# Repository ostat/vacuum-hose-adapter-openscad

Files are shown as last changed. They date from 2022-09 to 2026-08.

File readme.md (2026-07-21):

# Vacuum hose adapters for OpenSCAD

This is a collection of OpenSCAD modules that allow you to easily design and 3D
print adapters for pipes and tubes of various sizes. The main utilization of
these adapters is to connect a vacuum hose to a variety of different tools and
devices, such as power tools, sanders, and dust collectors.

This highly parametric module lets you create create custom adapters that
perfectly fit the dimensions of your vacuum hose and the tool or device you want
to connect it to. Besides fitting the dimensions, it is also possible to design
the adapters with a tapered shape that ensures a secure and snug fit, preventing
any air leaks that might reduce the suction power of your vacuum.

# Availability
Official availability
 - Online: https://hose-adapter.ostat.com/vacuum-hose-adapter
 - Printables: https://www.printables.com/model/316283-vacuum-nozzles-for-all-common-hose-sizes
 - MakerWorld: https://makerworld.com/en/models/481868-parametric-vacuum-hose-connector#profileId-396315

# Documentation
Official documentation
- https://docs.ostat.com/docs/openscad/hose-adapter

## Connection types

Three different types of connections are possible to maximize the number of
applications possible.

### Hose connection
Intended for connection between two hoses or a hose and a tool exhaust.

#### Main settings
* Diameter: Internal or external diameter of the intended connector.
* Length: The length of the connection end.
* Taper: the hose connection can be tapered to allow for a tighter fit.

### Flat connection
Intended for connection to a tool. To achieve this the transition section is set
to flat, the transition length becomes the thickness. The flat area will be from
connector1Diameter to connector2Diameter.

#### Main settings
* TransitionStyle: **flat**
* TransitionLength: Thickness of the flat area.

### Magnetic flange connection
Intended for creating a quick removable connection that holds in place using
magnets. Perfect for quick connect/disconnect to large shop equipment.

The magnets should be slightly recessed so that the two faces get a good seal,
allow extra depth if you want to avoid supports. Usually 8 10mm x 1.5mm magnets
seem sufficient to hold a 50mm connector for a shopvac.

#### Magnet polarity
If you plan on connecting two magnetic flanges together, pay attention to the
polarities of your magnets. A good way to ensure connection would be to
**alternate the polarity** when gluing the magnets. That way it will always be
possible to connect any magnetic flange to an other one.

#### Alignment ring
An alignment ring can be added to help align the duct and reduce air leakage.
Ideally, the flange should be created with a small recess to accept the ring.
The most optimal solution would be to print the ring in flexible material (TPU).

Although, this does not appear to be required to have a good suction.

#### Main settings
**Changing any of the settings** (diameter, magnet size, alignment ring...)
**will change the magnet position and flange size**.
A good practice would be to save the configuration of the hose in JSON using the
`save preset` option in OpenSCAD. See [the OpenSCAD
documentation][openscad_save_params] for more information.

* Flange diameter: Internal diameter of the flange connection.
* Flange thickness: The overall thickness of the flange. Magnet thickness plus
  4mm seem to work well.
* Connector length: The length of the connector before the tapered section will
  start.
* Magnet count: Number of magnets to be added to the flange.
* Magnet diameter: Diameter of the magnets (add 0.5 to measurement).
* Magnet border: The amount material around the magnet.
* Magnet thickness: Thickness of the magnets (add 0.5 to measurement, 1.0 to
  avoid supports).
* lip: If an alignment ring should be supported, can be recessed or protruding,
  suggest recessed.

## Sample files
The file [vacuum-hose-adapter-samples.scad](vacuum-hose-adapter-samples.scad
"more info"), has a few sample configurations to highlight the intended usages.

### 50mm hose to 30mm hose
An adapter to connect a 50mm (internal diameter) hose to a 30mm (internal
diameter) hose. A stop is added to the larger 50mm side, so the adapter does not
get pulled in to the hose. Both ends have a small taper to ensure snug fit.<br>
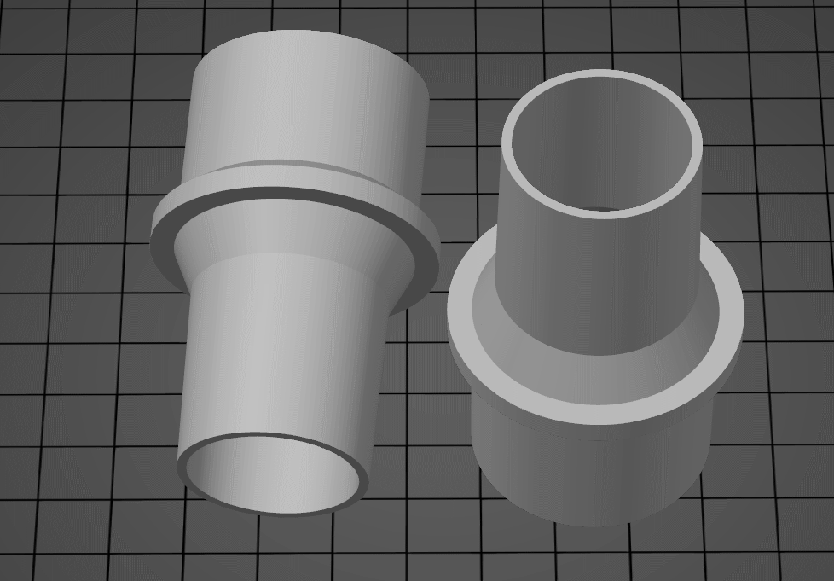
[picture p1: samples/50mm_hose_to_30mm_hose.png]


### 50mm hose to 100mm hose
An adapter to connect a 50mm (internal diameter) hose to a 100mm (internal
diameter) hose. A stop is added to the larger 100mm side, so the adapter does
not get pulled in to the hose. Both ends have a small taper to ensure snug
fit.<br>
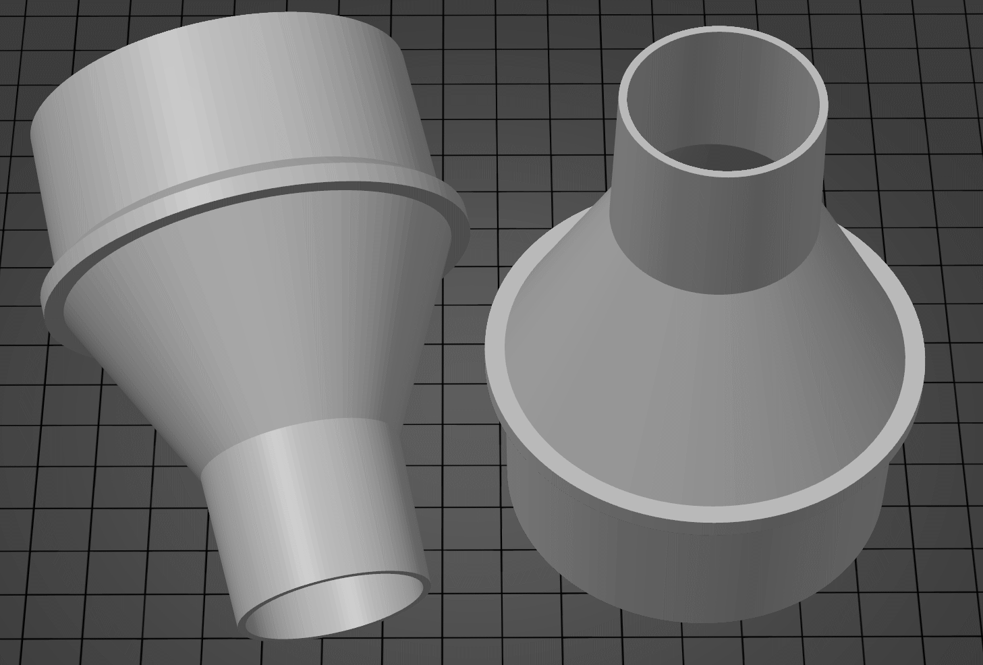
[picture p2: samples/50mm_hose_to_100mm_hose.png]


### Flat plate to 50mm hose
An adapter to connect a 50mm (internal diameter) host to the side of a something
else such as a large tool or machine. The end has a small taper.<br>
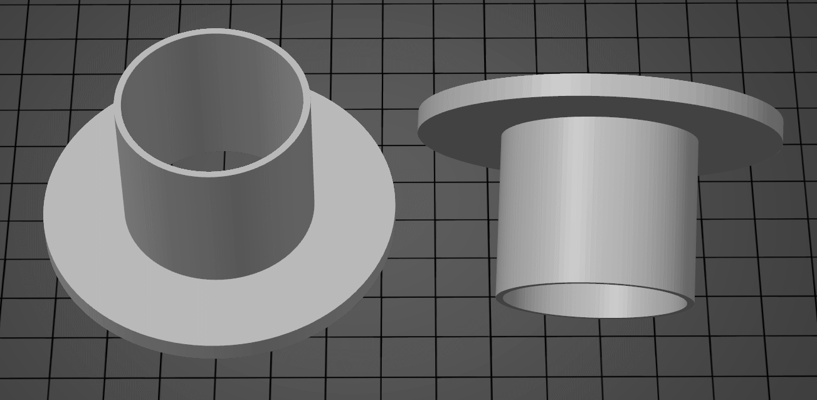
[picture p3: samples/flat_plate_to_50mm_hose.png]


### 50mm magnet to 40mm
A 50mm magnetic adapter to a 40mm hose. The magnetic flange has space for 8 10mm
x 2mm magnets (magnet holes are 10.5mm x 2.5mm). There is a recessed ring for an
alignment ring. The 40mm end has a 2mm taper.<br>
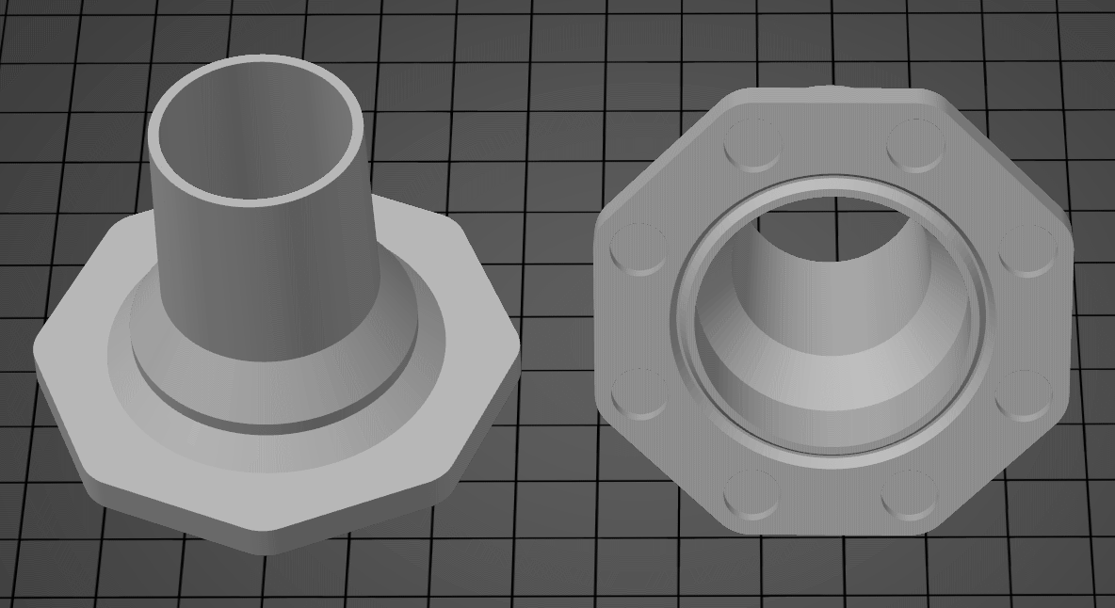
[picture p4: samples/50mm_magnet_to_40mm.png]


### 50mm magnet to 100mm
A 50mm magnetic adapter to a 100mm hose. The magnetic flange has space for 8
10mm x 2mm magnets (magnet holes are 10.5mm x 2.5mm). There is a recessed ring
for an alignment ring. The 100mm end has a 2mm taper.<br>
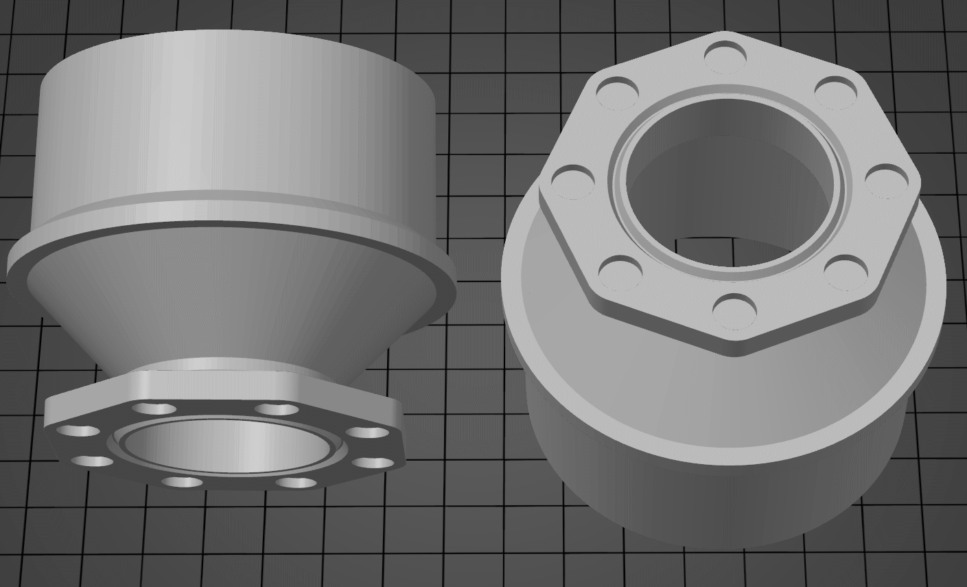
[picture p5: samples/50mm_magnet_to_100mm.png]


### 50mm magnet to flat plate with 30mm connector
A 50mm magnetic adapter to flat plate with 30mm connector. The magnetic flange
has space for 8 10 mm x 2mm magnets (magnet holes are 10.5mm x 2.5mm). This can
be used to for connecting to a tool that would have a hole the size of the
connector.<br>
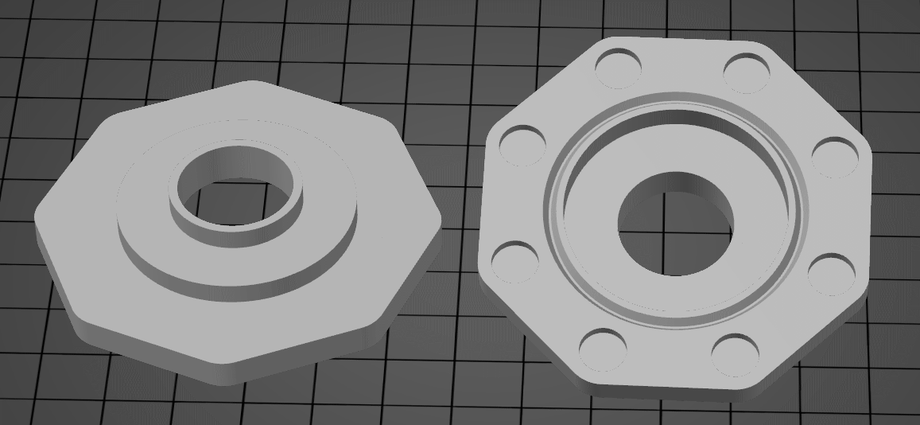
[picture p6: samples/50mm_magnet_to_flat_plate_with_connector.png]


### 50mm magnet to flat plate
A 50mm magnetic adapter to flat plate. The magnetic flange has space for 8 10mm
x 2mm magnets (magnet holes are 10.5mm x 2.5mm). This can be used as an
attachment point on the side of tool box.<br>
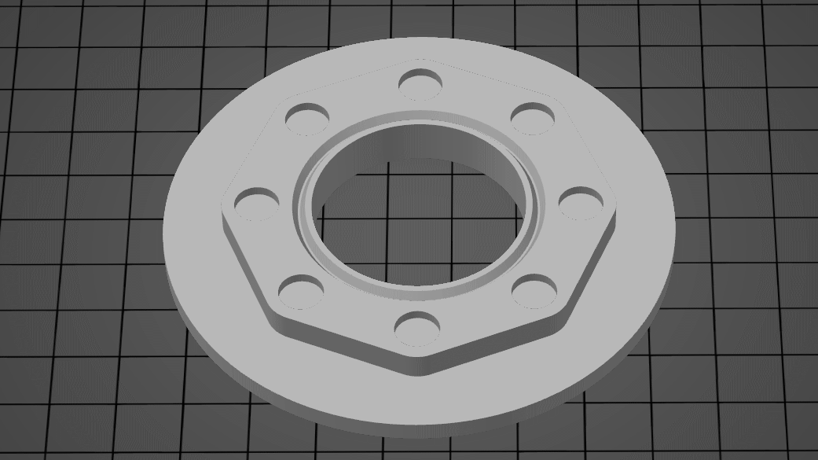
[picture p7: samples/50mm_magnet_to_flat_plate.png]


### 50mm magnet flange alignment ring
A alignment ring that fits in the recess on 50mm magnetic adapter. Ideally this
would be printed in a soft plastic like TPU so it can act as a seal. The ring is
slightly smaller in width and height to allow for imperfections in the print. I
found its not really needed.<br>
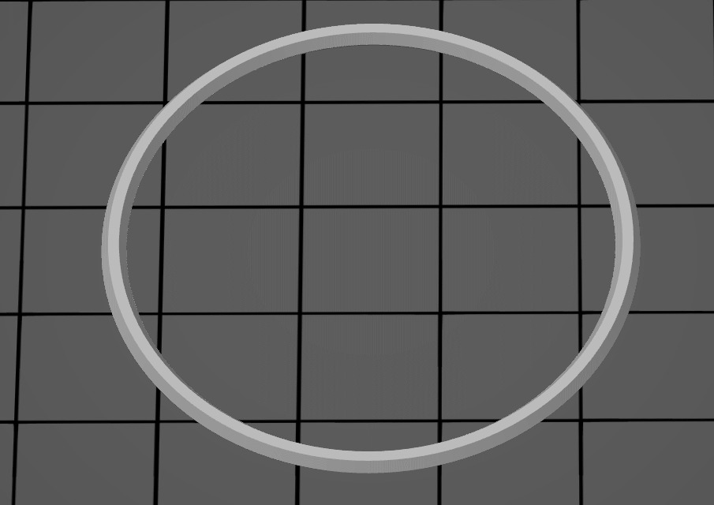
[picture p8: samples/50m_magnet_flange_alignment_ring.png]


### 100mm magnet flange to 50mm hose
A 100mm magnetic adapter to a 50mm hose. The magnetic flange has space for 12
10mm x 2mm magnets (magnet holes are 10.5mm x 2.5mm). There is a recessed ring
for an alignment ring. The 50mm end has a 2mm taper and a hose stop.<br>
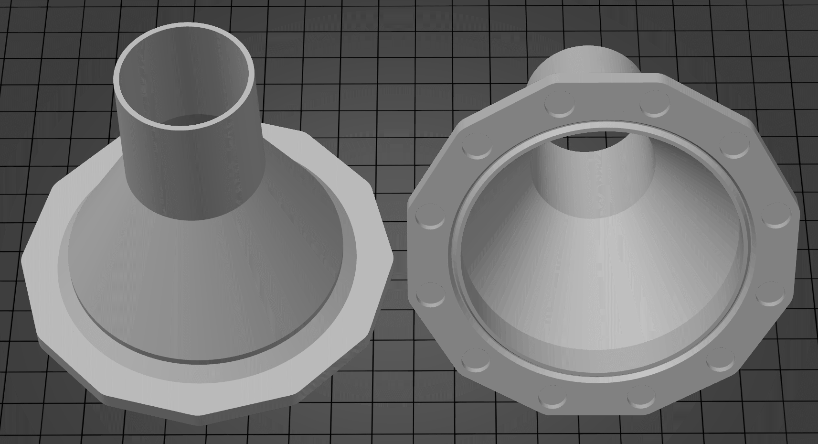
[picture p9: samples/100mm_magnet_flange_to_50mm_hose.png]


### 100mm magnet flange to 100mm hose
A 100mm magnetic adapter to a 100mm hose adapter. The magnetic flange has space
for 12 10mm x 2mm magnets (magnet holes are 10.5mm x 2.5mm). There is a recessed
ring for an alignment ring. The 100mm end has a 2mm taper and a hose stop.<br>
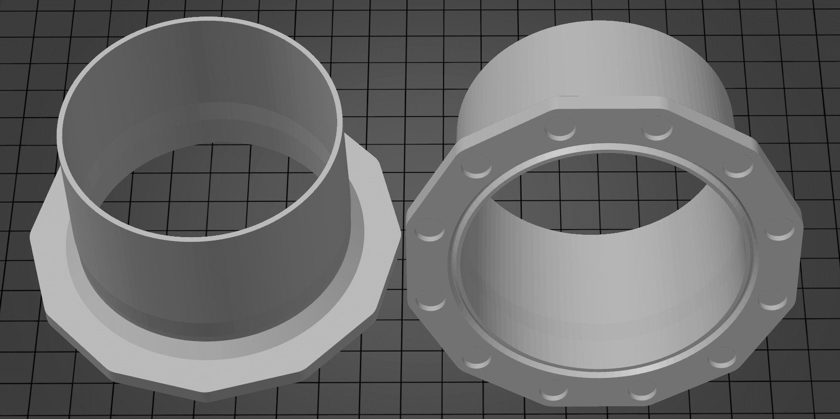
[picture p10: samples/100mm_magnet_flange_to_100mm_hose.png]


### 100m magnet flange alignment ring
A alignment ring that fits in the recess on 100mm magnetic adapter. Ideally this
would be printed in a soft plastic like TPU so it can act as a seal. The ring is
slightly smaller in width and height to allow for imperfections in the print. I
found its not really needed.<br>
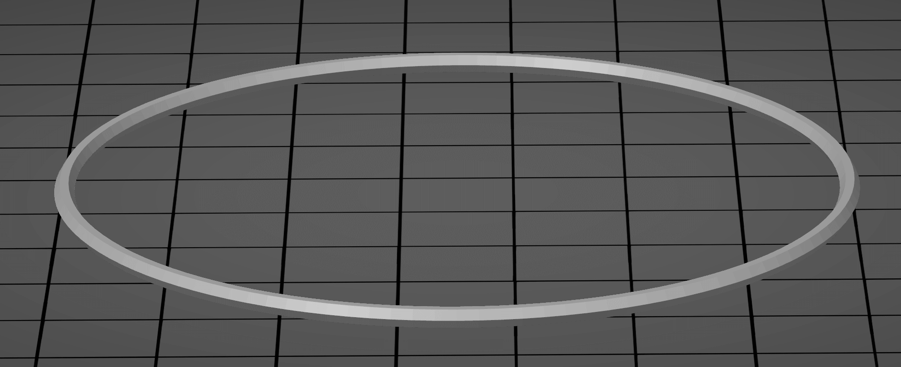
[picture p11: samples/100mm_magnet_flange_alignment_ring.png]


### 50mm magnet to 100mm magnet
A 50mm magnetic connector to a 100mm magnetic flange. Allowing connection
between different sized magnetic connectors.<br>
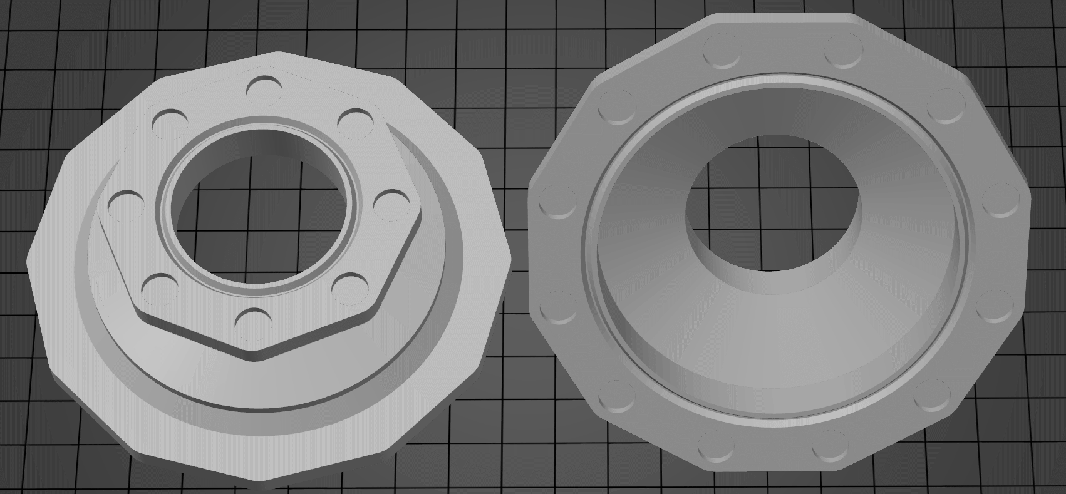
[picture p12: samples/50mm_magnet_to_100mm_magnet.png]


[openscad_save_params]:https://en.wikibooks.org/wiki/OpenSCAD_User_Manual/Customizer#GUI

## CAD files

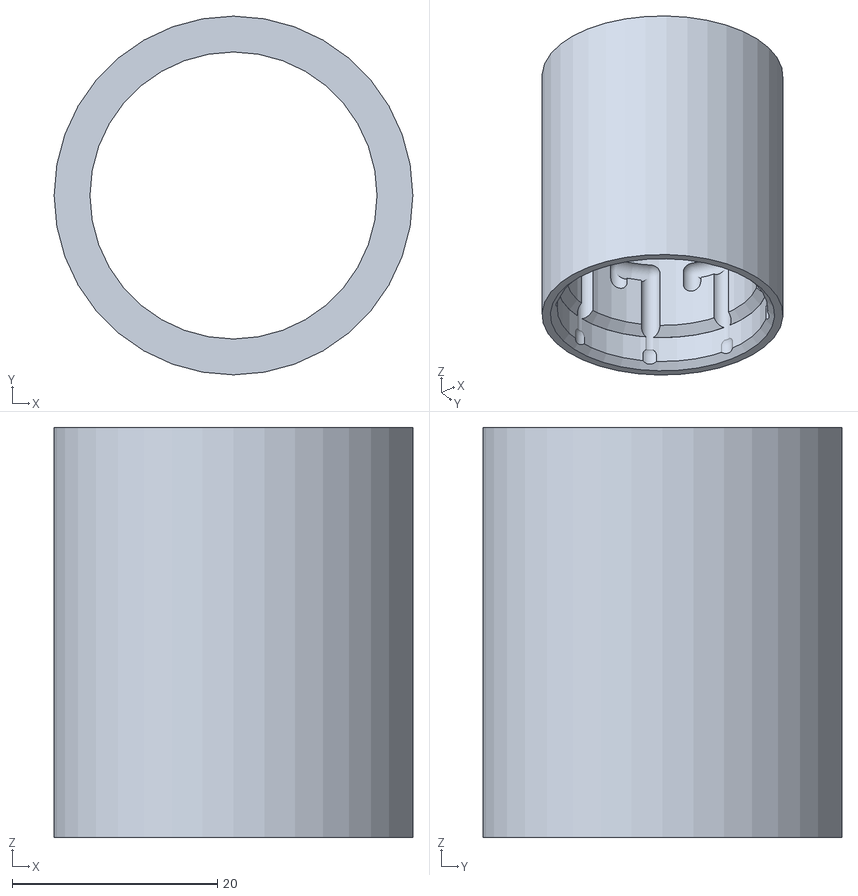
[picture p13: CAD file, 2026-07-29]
samples/bosch_sander_sample_low_res.stl
35.0 x 35.0 x 40.0

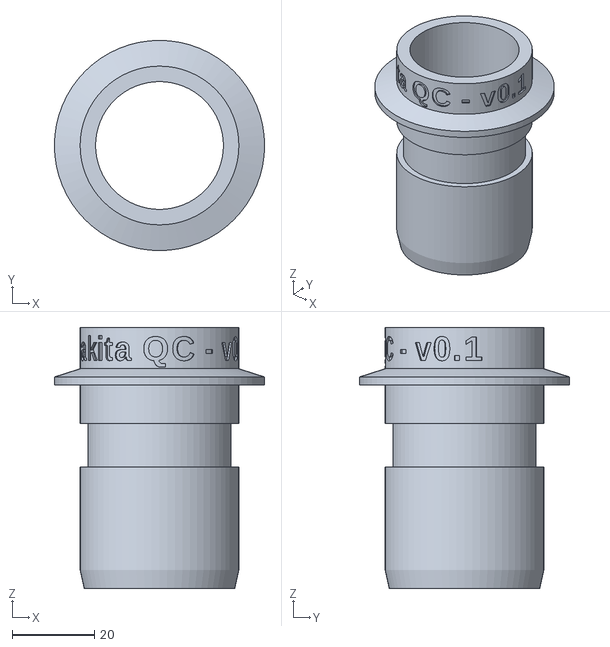
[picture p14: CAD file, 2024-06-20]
samples/makita_male_sample.stl
51.0 x 51.0 x 63.3

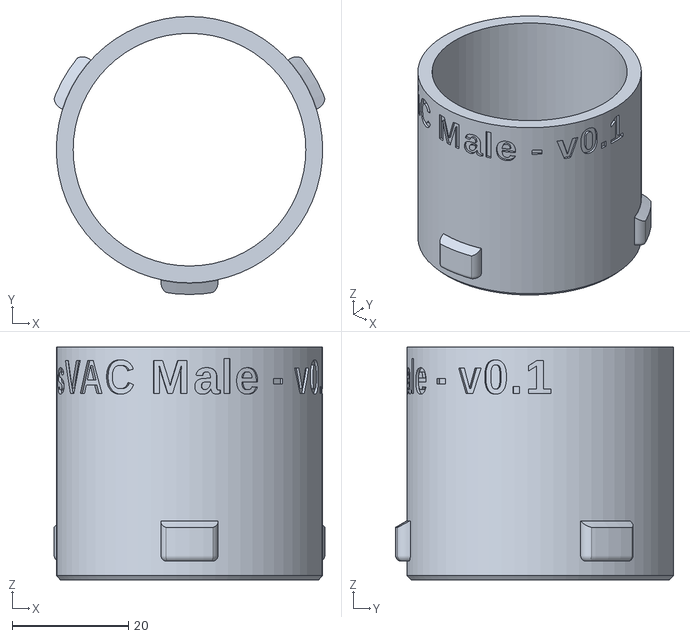
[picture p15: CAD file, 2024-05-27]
samples/osvacm_sample.stl
46.5 x 47.8 x 40.0

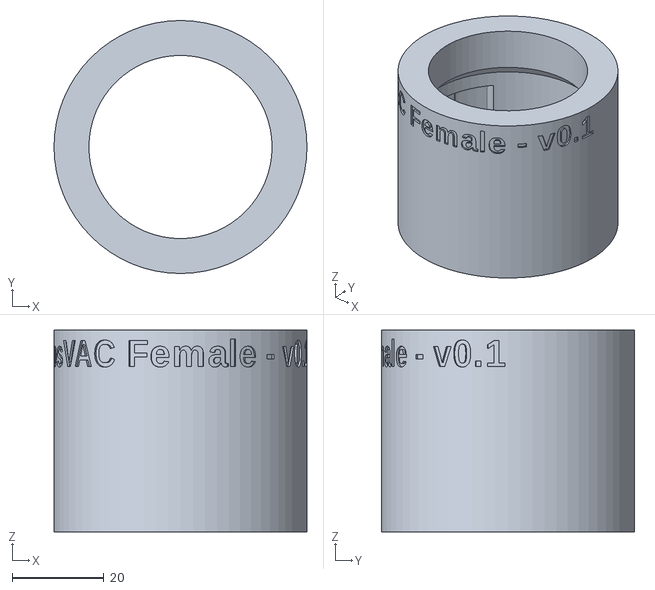
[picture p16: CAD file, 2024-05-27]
samples/osvacf_sample.stl
55.3 x 55.3 x 44.1

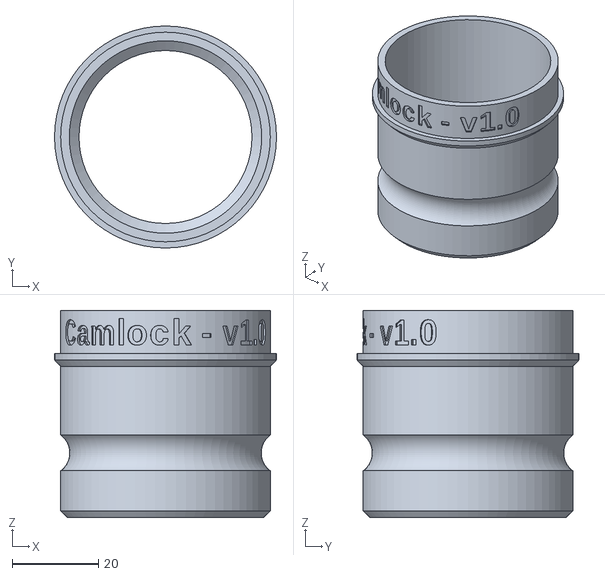
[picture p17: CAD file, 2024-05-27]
samples/camlock_sample.stl
51.4 x 51.4 x 48.0

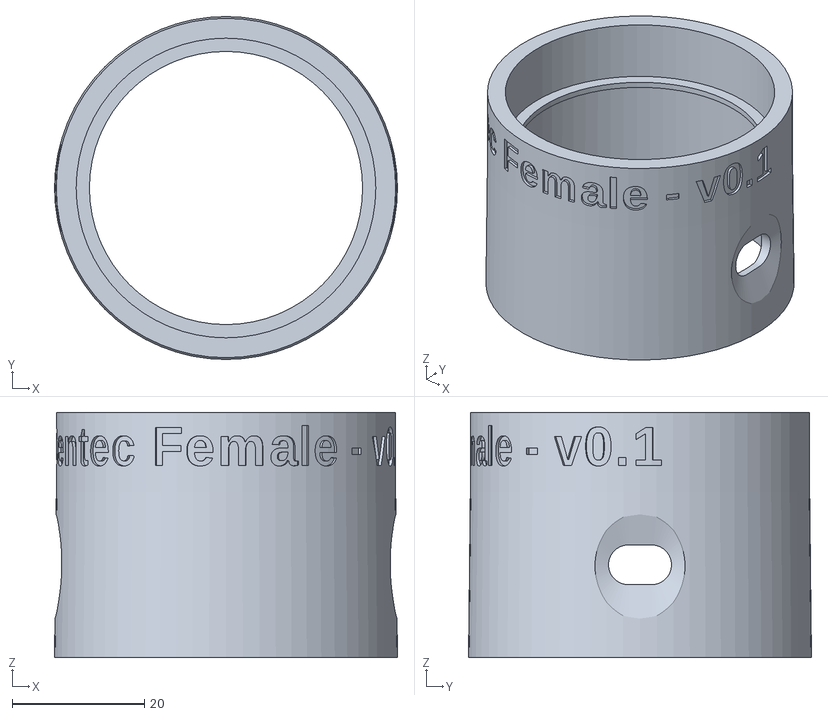
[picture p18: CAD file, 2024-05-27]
samples/centec_female_sample.stl
51.8 x 51.8 x 37.0

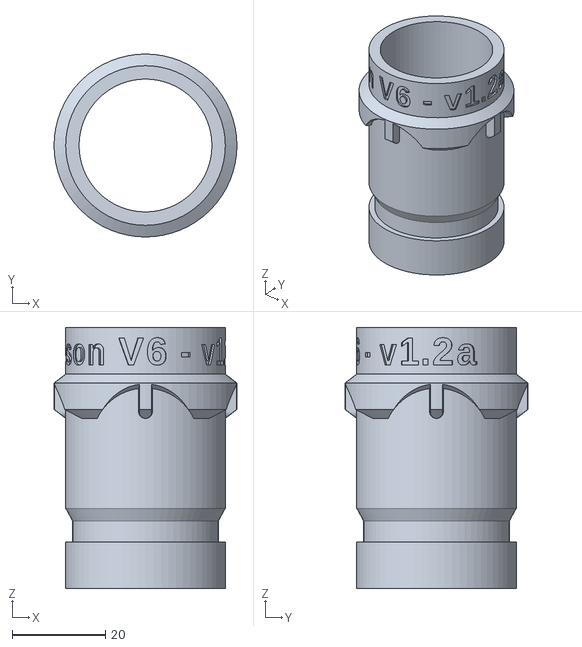
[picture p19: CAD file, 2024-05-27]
samples/dyson_sample.stl
39.2 x 39.2 x 56.0

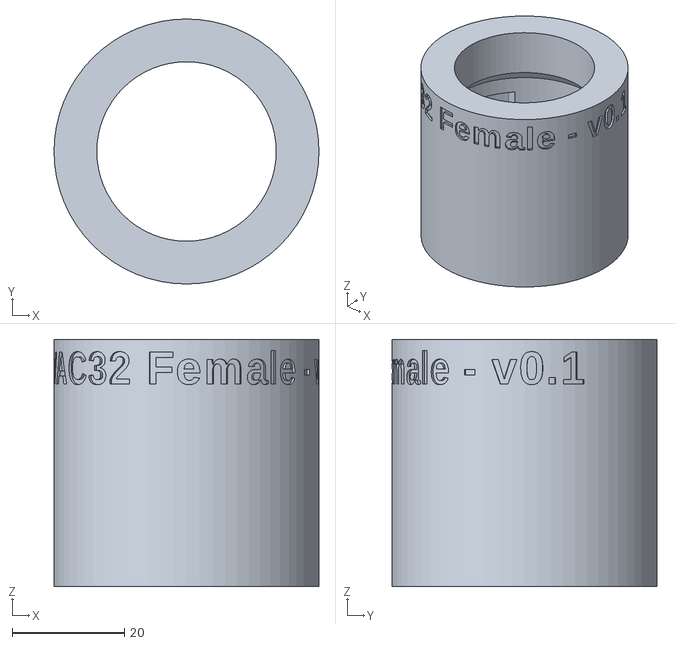
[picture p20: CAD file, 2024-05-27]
samples/osvacf32_sample.stl
47.3 x 47.3 x 44.1

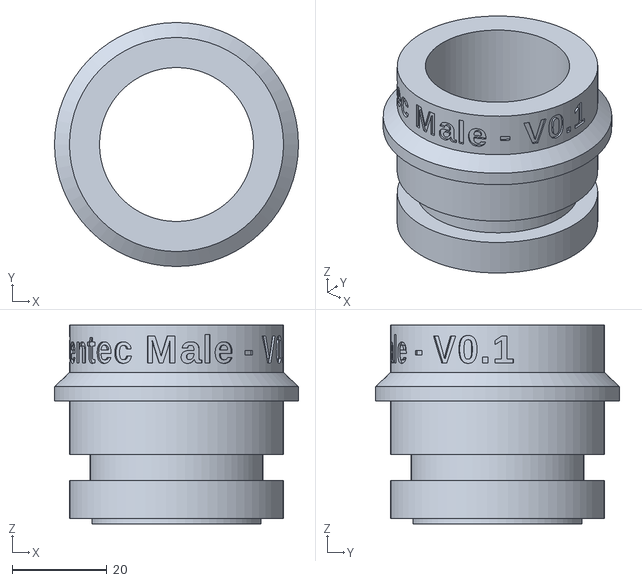
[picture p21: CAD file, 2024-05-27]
samples/centec_male_sample.stl
51.6 x 51.6 x 42.0

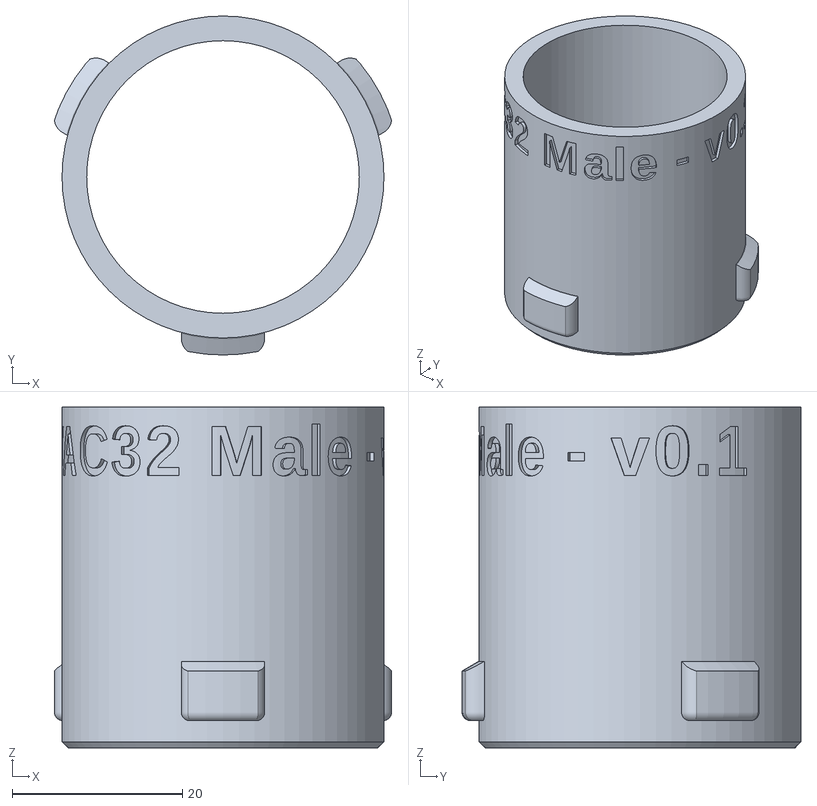
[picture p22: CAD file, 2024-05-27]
samples/osvacm32_sample.stl
39.6 x 39.8 x 40.0

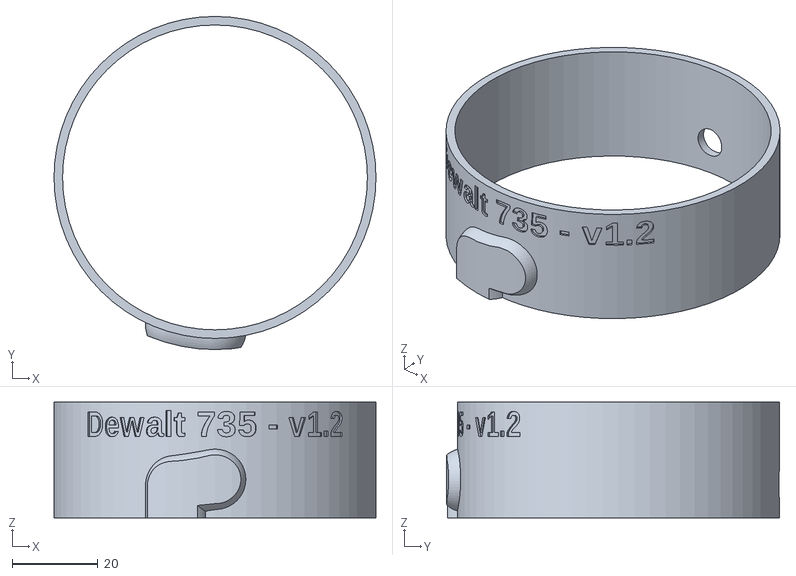
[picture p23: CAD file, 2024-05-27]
samples/dw735_sample.stl
75.0 x 77.6 x 27.0

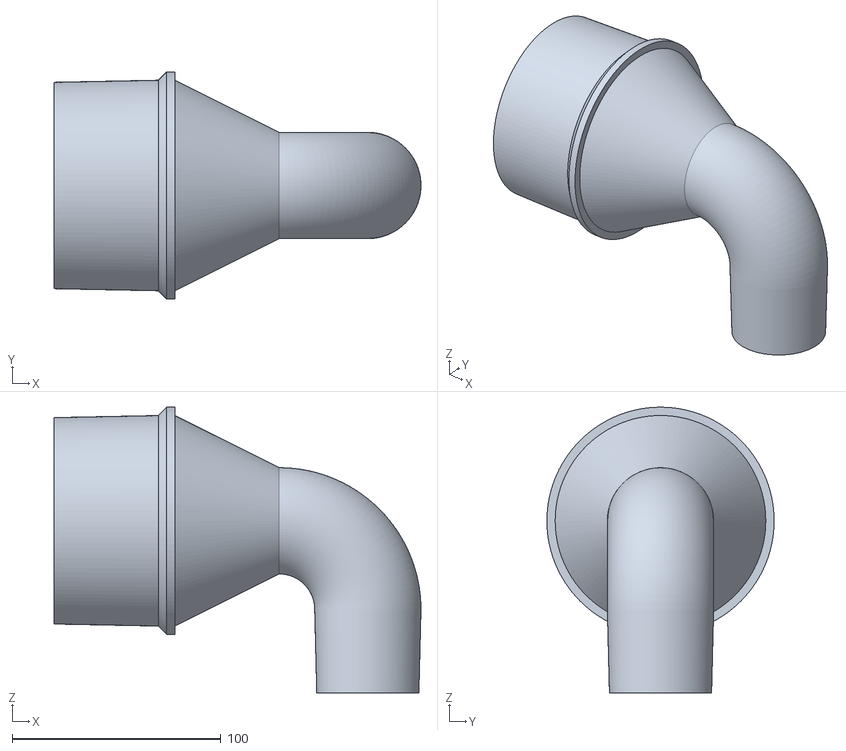
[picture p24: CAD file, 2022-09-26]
samples/50mm_hose_to_100mm_hose_bent_by_90deg.stl
176.0 x 109.0 x 137.0

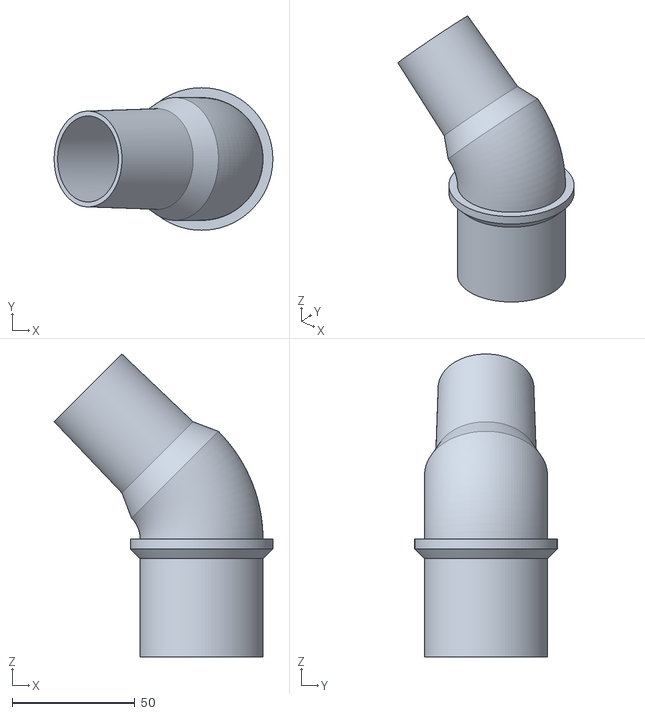
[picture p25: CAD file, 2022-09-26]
samples/50mm_hose_to_30mm_hose_bent_by_45deg.stl
89.0 x 58.0 x 123.3

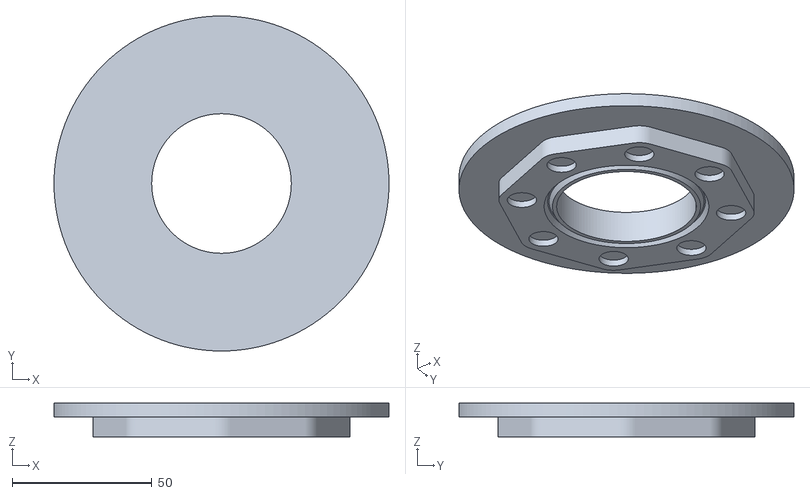
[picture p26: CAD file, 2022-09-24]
samples/50mm_magnet_to_flat_plate.stl
120.0 x 120.0 x 12.0

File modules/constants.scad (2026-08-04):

fudgeFactor = 0.015;

//Connector array settings
iSettingsLength = 0;
iSettingsMeasurement = 1;
iSettingsDiameter = 2;
iSettingsWallThickness = 3;
iSettingsTaper = 4;
iSettingsVersion = 5;

DefaultEnd1Color = "LightPink";
DefaultEnd1ExtensionColor = "HotPink";

DefaultEnd2Color = "SkyBlue";
DefaultEnd2ExtensionColor = "DeepSkyBlue";

DefaultEnd3Color = "MediumPurple";
DefaultEnd3ExtensionColor = "DarkOrchid";

DefaultTransitionColor = "LightGreen";
DefaultExtensionColor = "purple";

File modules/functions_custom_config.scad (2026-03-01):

include <functions_string.scad>

//Takes a string and converts it in to an array of arrays.
//I.E.  "0, 0, 0.5, 3, 2, 6|0.5, 0, 0.5, 3,2, 6|1, 0, 3, 1.5|1, 1.5, 3, 1.5";
//becomes  [[0, 0, 0.5, 3, 2, 6], [0.5, 0, 0.5, 3, 2, 6], [1, 0, 3, 1.5], [1, 1.5, 3, 1.5]]
function splitCustomConfig(customConfig) = let(
  compartments = split(customConfig, "|")
) [for (x =[0:1:len(compartments)-1]) csv_parse(compartments[x])];

function outputCustomConfig(typecode, arr) = let(
  config = createCustomConfig(arr),
  dynamicConfig = str("\"", typecode,"\"", ",", config)
) str("🟦 Generating 'tray' config, to be used in custom config.\r\nLocal Config\r\n\t", config, "\r\nDynamic Config\r\n\t", dynamicConfig,"\r\n");

function createCustomConfig(arr, pos=0, sep = ",") = pos >= len(arr) ? "" :
  let(
    current = is_list(arr[pos]) ? createCustomConfig(arr[pos], sep=";")
      : is_string(arr[pos]) ? str("\"",arr[pos],"\"")
      : arr[pos],
    strNext = createCustomConfig(arr, pos+1, sep)
  ) str(current, strNext!=""?str(sep, strNext):"");

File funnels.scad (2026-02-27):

// funnel
// version 2026-02-27

use <modules/vacuum-hose-adapter.scad>

/* [Funnel] */
//funnel opening diameter
OpeningDiameter = 20; //0.01

//Size of the hole for hanging
HangingHoleDiameter = 5;
//Length of the main funnel section. Default is the difference of opening and tip, to five 45deg walls.
FunnelLength = 0;
//Thickness of the funnel walls
WallThickness = 1.5; // 0.1

/* [Funnel advanced] */
//Angle of the spout
SpoutAngle = 0;
//Where should the angle be applied
TransitionStyle = "taper+bend"; //[taper+bend: Taper then bend, bend+taper: Bend then taper]
//Offset the spout in the x direction
SpoutOffset = [0,0];

/* [Spout] */
//Internal Diameter of the spout tip
SpoutTipDiameter = 5;
//Length of the spout tip. Default is related to funnel length.
SpoutTipLength = 0;
//Wall thickness of the spout tip
SpoutTipWallThickness = 0.6;

/* [Spout advanced] */
// Pre tip length of the spout.
SpoutLength = 1;
// Pre tip internal diameter of the spout.
SpoutDiameter= 0;

/* [Hidden] */
FlangeThickness = 1.5; // 0
ScrewBorder = 3;

//Detail
$fn=120;

module end_of_customizer_opts() {}

//Apply defaults
transitionLength = FunnelLength < 1 ? (OpeningDiameter-SpoutDiameter)/2 : FunnelLength;
spoutTipLength = SpoutTipLength < 1 ? transitionLength*1.5 : SpoutTipLength;
spoutLength = SpoutLength < 1 ? 1 : SpoutLength;
spoutDiameter = SpoutDiameter < 1 ? SpoutTipDiameter : SpoutDiameter;

  HoseAdapter(
      connector1 = UserConnectorSettings(
        connector=1,
        style="flange",
        wallThickness=WallThickness,
        measurement="inner",
        diameter=OpeningDiameter,
        length=3,
        flangeWidth=7,
        flangeThickness=FlangeThickness,
        flangeScrewPosition=WallThickness * 2 + HangingHoleDiameter + ScrewBorder,
        flangeScrewBorder=ScrewBorder,
        flangeScrewCount=1,
        flangeScrewDiameter=HangingHoleDiameter),

      transitionStyle = TransitionStyle,
      transitionLength = transitionLength,
      transitionOffset = SpoutOffset,
      transitionAngle = SpoutAngle,

      connector2 = UserConnectorSettings(
        connector=2,
        style="nozzle",
        wallThickness=WallThickness,
        measurement="inner",
        diameter=spoutDiameter,
        length=spoutLength,
        nozzleShape = "circle",
        nozzleTipWallThickness = SpoutTipWallThickness,
        nozzleRadius = SpoutTipDiameter/2,
        nozzleSize= [0,0,spoutTipLength],
        nozzleChamferPercentage = 100,
        nozzleChamferAngle = 30)
  );

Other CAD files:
samples/100mm_magnet_flange_to_50mm_hose.stl
samples/50mm_hose_to_30mm_hose.stl
samples/flat_plate_to_50mm_hose.stl
samples/50mm_magnet_to_100mm_magnet.stl
vacuum-hose-adapter-basic.scad
combined/funnels.scad
combined/vacuum-hose-adapter-basic.scad
combined/vacuum-hose-adapter-openscad.scad
combined/vacuum-hose-adapter.scad
demos/vacuum_hose_adapter_demo.scad
modules/connector_camlock.scad
modules/connector_centec.scad
modules/connector_dw735.scad
modules/connector_dyson.scad
modules/connector_flange.scad
modules/connector_hose.scad
modules/connector_magnetic.scad
modules/connector_makita.scad
modules/connector_nozzle.scad
modules/connector_osvac.scad
modules/connectors/connector_bosch_sander.scad
modules/connectors/connector_camlock.scad
modules/connectors/connector_centec.scad
modules/connectors/connector_common.scad
modules/connectors/connector_common_post.scad
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

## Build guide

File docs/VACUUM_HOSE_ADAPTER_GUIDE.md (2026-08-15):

# Agent & Developer Guide: Vacuum Hose Adapter OpenSCAD Library

This guide provides technical documentation for AI agents and human developers for utilizing, embedding, or extending the `vacuum-hose-adapter-openscad` library.

---

## 1. Including the Library

In your OpenSCAD scripts, include the primary library module:

```scad
include <modules/vacuum-hose-adapter.scad>
```

If including from an external repository (e.g. `openSCAD/my_project/my_project.scad`), use relative pathing:

```scad
include <../../vacuum-hose-adapter-openscad/modules/vacuum-hose-adapter.scad>
```

---

## 2. Core API Architecture

The entry function for constructing dual-connector adapters is `HoseAdapter()`. It consumes two connector object structures constructed via `UserConnectorSettings()`.

```scad
HoseAdapter(
  connector1 = UserConnectorSettings(...),
  connector2 = UserConnectorSettings(...),
  transitionStyle = "bend+taper", // "flat", "taper+bend", "bend+taper", "organicbend", "hull", "none"
  transitionLength = 0,            // Length of transition section in mm
  transitionBendRadius = 0,        // Bend radius in mm
  transitionAngle = 0,             // Angle of transition bend in degrees
  transitionOffset = [0, 0],       // [X, Y] offset in mm
  
  sliceDebug = false,              // Cutaway view for debugging interior
  showCaliper = false,             // Render dimension calipers
  end1Color = ["", 1],
  end2Color = ["", 1],
  transitionColor = ["", 1]
);
```

---

## 3. Parameter Dictionary (`UserConnectorSettings`)

### Common Options
- `connector`: `1` or `2`.
- `style`: Connector type (see Section 4).
- `wallThickness`: Main wall thickness in mm (default `2`).
- `measurement`: `"outer"` (OD for inserting into hose/port) or `"inner"` (ID for fitting over pipe).
- `diameter`: `[mm, inch]` tuple, e.g., `[50, 0]`.
- `length`: `[mm, inch]` tuple, e.g., `[40, 0]`.
- `taper`: Taper angle in mm. Positive tapers outward toward end.
- `rotation`: Rotation angle around Z-axis in degrees.

### Hose Connector Options (`style = "hose"`)
- `stopThickness`: Thickness of hose stop ring (mm). `0` disables stop.
- `stopLength`: Length of hose stop ring (mm).
- `stopSymmetrical`: `true`/`false` - taper both sides of stop.
- `barbsCount`: Number of retention barbs.
- `barbsThickness`: Height/thickness of barbs (mm).
- `barbsSymmetrical`: `true`/`false`.
- `endCapThickness`: Debris cap thickness (mm). `0` disables cap.
- `endCapGridSize`: Grid hole size for debris cap (mm).
- `enableThreads`: `"disabled"`, `"enabled"` (left-hand thread), or `"reversed"` (right-hand thread).
- `threadPitch`: Pitch in mm.

### Magnetic Flange Options (`style = "mag"`)
- `magnetCount`: Number of magnet pockets.
- `magnetDiameter`: Hole diameter in mm (add 0.3–0.5mm clearance, e.g., `10.5` for 10mm magnet).
- `magnetThickness`: Pocket depth in mm (add 0.3–0.5mm clearance, e.g., `2.5` for 2mm magnet).
- `magnetBorder`: Extra wall material around magnet pockets (mm).
- `flangeThickness`: Total flange face thickness (mm).
- `alignmentRing`: `"no"`, `"recessed"`, or `"protruding"`.

### Screw Flange Options (`style = "flange"`)
- `flangeWidth`: Added flange width relative to connector diameter (mm).
- `flangeThickness`: Flange plate thickness (mm).
- `screwCount`: Number of screw holes.
- `screwDiameter`: Hole diameter in mm (e.g. `4.5` for M4).

### Nozzle Options (`style = "nozzle"`)
- `nozzleShape`: `"round"`, `"rectangle"`, or `"oval"`.
- `nozzleSize`: `[width, depth, height]` vector for tip opening.
- `nozzleRadius`: Corner rounding radius (mm).
- `nozzleChamferAngle`: Bevel angle at tip end (degrees).

---

## 4. Supported Connector Styles

| Style Code | Description |
|---|---|
| `"hose"` | Standard smooth, tapered, barbed, or threaded hose connector |
| `"mag"` | Quick-disconnect magnetic flange with magnet pockets |
| `"flange"` | Mounting flange with screw holes for tool bodies |
| `"osvacm"`, `"osvacm32"` | osVAC male quick-connect coupler |
| `"osvacf"`, `"osvacf32"` | osVAC female quick-connect coupler |
| `"centec_male"`, `"centec_female"` | Cen-Tec quick disconnect system |
| `"makita_male"` | Makita tool vacuum port connector |
| `"dyson"` | Dyson cordless tool latching attachment |
| `"camlock"` | Camlock quick disconnect fitting |
| `"dw735"` | DeWalt DW735 planer dust port adapter |
| `"kobalt"` | Kobalt saw dust outlet female socket with recessed ring channels |
| `"rigid_nxt"` | Rigid NXT shop vac hose connector with locking ridges |
| `"nozzle"` | Crevice tool, wide nozzle, or utility vacuum nozzle |
| `"none"` | Open or flat end |

---

## 5. Standard Code Recipes

### Recipe 1: 50mm to 35mm Hose Adapter
```scad
include <modules/vacuum-hose-adapter.scad>

$fa = 3;
$fs = 0.1;

HoseAdapter(
  connector1 = UserConnectorSettings(
    connector = 1,
    style = "hose",
    wallThickness = 2.5,
    measurement = "outer",
    diameter = [50, 0],
    length = [35, 0],
    taper = 1,
    stopThickness = 1.5,
    stopLength = 3,
    stopSymmetrical = true
  ),
  connector2 = UserConnectorSettings(
    connector = 2,
    style = "hose",
    wallThickness = 2.5,
    measurement = "inner",
    diameter = [35, 0],
    length = [30, 0],
    taper = 0.5
  ),
  transitionStyle = "bend+taper",
  transitionLength = 15
);
```

### Recipe 2: Magnetic Flange to Hose
```scad
include <modules/vacuum-hose-adapter.scad>

$fa = 3;
$fs = 0.1;

HoseAdapter(
  connector1 = UserConnectorSettings(
    connector = 1,
    style = "mag",
    wallThickness = 2.5,
    measurement = "outer",
    diameter = [50, 0],
    length = [20, 0],
    magnetCount = 8,
    magnetDiameter = 10.5,
    magnetThickness = 2.5,
    magnetBorder = 3,
    flangeThickness = 6,
    alignmentRing = "recessed"
  ),
  connector2 = UserConnectorSettings(
    connector = 2,
    style = "hose",
    wallThickness = 2.5,
    measurement = "outer",
    diameter = [40, 0],
    length = [35, 0],
    taper = 1
  ),
  transitionStyle = "bend+taper",
  transitionLength = 15
);
```

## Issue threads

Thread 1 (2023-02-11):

Samples not working

pagu99, 2023-02-11:
Almost all samples I tried have the issue, that the parts of the adapter are not connected. Attached a screenshot from the 50to30 sample.
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

lambtho12, 2023-02-25:
Commit https://github.com/ostat/vacuum-hose-adapter-openscad/commit/93847063d72d07553f232268277486688d68d1ce
removed the simple `tapered` option for `transitionStyle`. It should be replaced by `bend+taper` in the samples to make them work again.

See my PR #3 for the fixed version of this file. (The rest of the PR is not needed for it to work, only that small adaptation to the `samples.scad` files is.)

Will-Beninger, 2023-02-26:
New to OpenSCAD so was banging my head against the wall. Knew I should have checked the PRs/Issues. Great fix, I've moved over to your dev branch until PR is approved.

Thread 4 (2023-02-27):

[Feature Request] Add a loop/ring so the adapter can be hooked for storage

lambtho12, 2023-02-27:
It would be nice to have a simple boolean option to add a loop or ring on the side of the adapter.
This would allow to bundle all the adapters using a string or something and simply hook them on the wall instead of taking valuable space on my shelves.

ostat, 2023-03-27:
Nice idea, any thoughts on a design? I feel like it could be something that was added with or near the stop ring?

lambtho12, 2023-03-27:
The ring could be added either near one of the ends (providing it is external fit and not internal, I do not know if that makes sense) or near the stop ring indeed. This could be set using options. The ring thickness should be 3-4 mm, no need for more.

Options could include a toggle to display the ring or not, the ring inner diameter and the position and a the orientation of the ring along the main axis of the adapter (or simply always put it in the opposite side of the bend and remove the orientation option).

```openscad
// Ring to hook the adapter for storage
Ring = false;
// Ring inner diameter
RingD = 8; // [5:1:15]
// Position of the ring
RingPos = "StopRing"; //["StopRing" = "Stop Ring", "End1", "End2"]
// Orientation of the ring along main axis
RingOrient = 0; //[0:5:360]
```

Now that I think of it, it could be even better to have different hooking systems (hook, ring, clamp, ...). All dimensions and position options could be reused but the type of attachment would be different.

ostat, 2023-03-27:
Some interesting ideas. The last one could be made printable without support which is nice. Will think about it some more,

Checked out your library. You have some great ideas in there. That is going to come in handy for a lot of people.

lambtho12, 2023-03-28:
> Checked out your library. You have some great ideas in there. That is going to come in handy for a lot of people.

Thank you. It is my first proper openscad project, so there is probably a ton of room for improvement. But indeed, this should be quite useful I believe. I will work on a script to automate the part creation so I can post all of that on printables or something in the near future.

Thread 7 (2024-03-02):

Support CenTec adapter

ostat, 2024-03-02:
Add support for CenTec connector system

landrypm, 2024-03-07:
(Also messaged you on Printables.)

I printed two couplers last night and the fit is very good. Here is a link to a Google Photos album with a few pictures and one short video using the test coupler. I also printed one other and the size was perfect but the holes for the retaining clips were not working as well. I did not use supports and I think the "top" of the holes were not square and that is allowing the clip to slip out on one side. I will reprint with supports in the holes to confirm.

https://photos.app.goo.gl/H1gDvLU8k3u3sgJF9

It seemed that the fit to the printed coupler was equivalent to the fit with the commercial bought ones I have. As soon as I get a real coupler printed that I can use to connect to a tool I will be able to check for air loss. But I don't anticipate it to be any worse than with the commercial couplers.

Thanks so much for your time and talent. Let me know there is some way I can buy you a beer or lunch.

ostat, 2024-03-08:
thanks for the feedback, and detailed video.

I made some tweaks, that might help.

- Changed the pin hole corner radius from 1mm to 3mm
- Change the pin hole hole width from 11mm to 9.5
- Changed how the taper to the pin hole. Start is the same but end is almost flush. Should help prevent slipping out.
- Changed internal length from 25mm to 24mm
- Change internal radius from 22.67 to 22.3
- If we can make it fit snug, I think the pin will not fall out as easily.
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

[centec-test-print_V2.zip](https://github.com/ostat/vacuum-hose-adapter-openscad/files/14535484/centec-test-print_V2.zip)

Closed 2024-04-08.

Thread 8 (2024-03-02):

dw735 connector does not fit onto planer outlet

luisillo26, 2024-03-02:
As commented in printables, the dw735 connector don't fit onto the planer outlet.

I printed the test ring but unfortunately the fixed pin on the planer does not slide nicely to the bottom of any of the 4 "hooks" on the adapter so it gets stuck without letting the metal latch to engage on the other side. It looks like there is not enough clearance.

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

ostat, 2024-03-02:
Can you include a photo of the hole the pin should go into, interested to see how close the pin is to the hole?

luisillo26, 2024-03-02:
I added that photo in the PR

ostat, 2024-03-02:
Thanks.

I am surprised that shortening the pin fixed the issue. I expected that you would need to make the pin longer, to increase fixedPinLength for more hole depth for the pin, or adjust one of the other slot variables.

Was the issue that the fixed pin got stuck inside the slot, or was it the walls around the pin hole was hitting the plastic on the planer preventing it seating?

luisillo26, 2024-03-02:
Yeah, the slots walls prevented the adapter to fully seat because they were rubbing against the yellow plastic but making the slots slimmer fixed the issue. I'm printing the full version now, will update with the final picture

ostat, 2024-03-02:
This is what mine looks like. Not the best filament colour choice.

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

luisillo26, 2024-03-02:
That dust port looks a few millimeters longer than my planer, I guess that's why it didn't fit with the 1st test print

ostat, 2024-03-02:
Agreed, also you can see in mine that the lip under the sticker looks much bigger than yours. So there has been a revision in the design somewhere.

Do you think it would be worth doing something like this?

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

ostat, 2024-03-02:
re-opened to continue discussion, post accept of merge.

luisillo26, 2024-03-03:
I think either that option or having the option to completely exclude slot "covers" in [these lines](https://github.com/ostat/vacuum-hose-adapter-openscad/blob/4bec6f7580d9dfa97d7f7fa6cea9fd80005ea4a7/vacuum-hose-adapter-modules.scad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) by using another parameter/variable.

I printed it without the covers like the factory one, just like you said and it's held very well.

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

luisillo26, 2024-03-03:
Here is the full print with the changes from the merge, it printed away from perfect because I used supports with PETG which sucks but it's totally functional. The only thing I noticed is it's a little wobbly, it rocks up and down unlike the factory adapter, it must be because that one has a stop of 90 degrees from the internal wall where the slots are placed instead of the tapered one in you design.

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

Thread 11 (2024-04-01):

Debug slice feature has confusing numbers

akrly, 2024-04-01:
Hi,

When I set the "End2 Measurement" to outer the rendered number still displays the inner diameter value Arrows, text are fine. See attached screenshot.

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

lambtho12, 2024-04-08:
Sorry for offtopic, but how do you display the dimensions like that using openSCAD? Is there a library for it?

akrly, 2024-04-08:
Hey, no worries. Unfortunately it's not openSCAD functionality.

You'll find a debug option at the bottom of the config parameters menu. It splits the model if you enable it.

ostat, 2024-04-08:
> Sorry for offtopic, but how do you display the dimensions like that using openSCAD? Is there a library for it?

Its done creating standard openscad objects in the model. You can use the `$preview` flag to prevent them being included in the stl.
I use a modified version of the `UB.scad` library to create them.
https://github.com/ostat/vacuum-hose-adapter-openscad/blob/main/modules/ub.scad

ostat, 2024-04-08:
this is resolved

Closed 2024-04-08.

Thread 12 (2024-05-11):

Cen-Tec Hose-side Connector

vifino, 2024-05-11:
Hey, these adapters seem a lot higher quality than the models I found and happen to appear just at the right moment. Good job!

I would love to see the hose-side (with the clips) Cen-Tec connectors as well!
This would allow connecting to equipment that already uses such a connector, obviously.

Bosch's Click and Clean seems to use the same Cen-Tec style connectors, so it'd be useful for Bosch saws and such as well.

ostat, 2024-05-15:
> I would love to see the hose-side (with the clips) Cen-Tec connectors as well! This would allow connecting to equipment that already uses such a connector, obviously.
> Bosch's Click and Clean seems to use the same Cen-Tec style connectors, so it'd be useful for Bosch saws and such as well.

Hi, I think that was fixed in this updated a984a4a
Let me know if I misunderstood.
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

vifino, 2024-05-20:
Hey! The lower connector does indeed look like the hose side connector (Male?), but how do you get that one?

I would like a "Connector 1 - CenTec" option group that allows you to switch between Male/Hose Sleeve and the existing Female/Tool Side socket.
Centec seems to use Male/Female in the few places where they name it.

ostat, 2024-05-20:
Oh I misunderstood.
I have not modelled the male side of the Centec style connector. Only the female side.
I could try model it at some stage. It does not look that complex. Happy for submissions also :).

ostat, 2024-05-20:
I had a crack at the adapter, I have not tested this :)
changeset dd23c9c

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

ostat, 2024-07-11:
I believe this is good now, so will close this issue. Please re-open or create new ticket if you think the adapter needs updating

Closed 2024-07-11.

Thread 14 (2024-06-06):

Undefined Operation Error in Latest Files

fazi13, 2024-06-06:
Hello, I just grabbed the latest version of the files from main and it appears something has gone wrong.
I have the following errors when loading the vacuum-hose-adapter-openscad.scad and vacuum-hose-adapter-samples.scad

```
[WARNING: undefined operation (undefined / number) in file modules/connector_hose.scad, line 28](https://github.com/ostat/vacuum-hose-adapter-openscad/issues/28,C:/Users/Dylan/Documents/3d%20print/vacuum-hose-adapter-openscad-main/modules/connector_hose.scad)
[WARNING: undefined operation (undefined - number) in file modules/connector_hose.scad, line 37](https://github.com/ostat/vacuum-hose-adapter-openscad/issues/37,C:/Users/Dylan/Documents/3d%20print/vacuum-hose-adapter-openscad-main/modules/connector_hose.scad)
[WARNING: Unable to convert translate([0, 0, undef]) parameter to a vec3 or vec2 of numbers in file modules/connector_hose.scad, line 37](https://github.com/ostat/vacuum-hose-adapter-openscad/issues/37,C:/Users/Dylan/Documents/3d%20print/vacuum-hose-adapter-openscad-main/modules/connector_hose.scad)
[WARNING: undefined operation (bool + number) in file modules/connector_hose.scad, line 38](https://github.com/ostat/vacuum-hose-adapter-openscad/issues/38,C:/Users/Dylan/Documents/3d%20print/vacuum-hose-adapter-openscad-main/modules/connector_hose.scad)
[WARNING: undefined operation (undefined + number) in file modules/connector_hose.scad, line 46](https://github.com/ostat/vacuum-hose-adapter-openscad/issues/46,C:/Users/Dylan/Documents/3d%20print/vacuum-hose-adapter-openscad-main/modules/connector_hose.scad)
[WARNING: Unable to convert translate([0, 0, undef]) parameter to a vec3 or vec2 of numbers in file modules/connector_hose.scad, line 46](https://github.com/ostat/vacuum-hose-adapter-openscad/issues/46,C:/Users/Dylan/Documents/3d%20print/vacuum-hose-adapter-openscad-main/modules/connector_hose.scad)
```

The model also is not working, there is a large gap in the center.
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

I went back several commits and those files are working. I'm not sure what happened
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

ostat, 2024-07-11:
I believe this is fixed now can you please retest?

Closed 2024-10-08.

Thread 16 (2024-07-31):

Support threads

ostat, 2024-07-31:
Add thread support to the hose connector

akalderon, 2025-01-21:
Second that - threads for hose connectors - both external (male) and internal (female) inclusive of their specs such as length, protrusion and density would be highly useful

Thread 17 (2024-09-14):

Support for Festool hoses

Andor, 2024-09-14:
Hello! It would be very cool to add support for Festool hosts.
They have locking tabs, which is a little different from everything else.

ostat, 2024-09-14:
That should be doable.
Do they all have the same connector or are there many styles?
I have a Festool track saw so can test on that.

Andor, 2024-09-14:
As far as I know, they have two kinds of connectors: for smaller machinery and for bigger ones.
For instance, jigsaw CARVEX have a small one, and track saws (like TSC 55) have a bigger one.
Vacuum hoses ends are compatible with both.

There is also vaccum-side connector, but it is just a tube without any features.

Can't find exact specs with all the sizes, but maybe you can look up for existing models: https://www.printables.com/search/models?q=festool%20vacuum

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

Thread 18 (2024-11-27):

demo "vacuum_hose_adapter_demo.scad" failed with error on line 857

ebo, 2024-11-27:
It currently gives an error:
    vacuum_hose_adapter_demo.scad'.
    [ERROR: Parser error: syntax error in file vacuum_hose_adapter_demo.scad, line 857](https://github.com/ostat/vacuum-hose-
   adapter-openscad/issues/857,/home/ebo/.local/share/OpenSCAD/libraries/vacuum-hose-adapter-
   openscad/demos/vacuum_hose_adapter_demo.scad)
    Execution aborted

I am just currently playing, and noticed that the demo broke.

patsummit, 2025-07-23:
Today is my 1st day with openscad but it appears there is an extra comma (',') at the end of the line.  At least it seems to do something reasonable when I remove the comma.

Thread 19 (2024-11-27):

generated nozzle wall it too thin

ostat, 2024-11-27:
The wall is too thin

https://www.printables.com/model/316283-vacuum-nozzles-for-all-common-hose-sizes/comments/2212028

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

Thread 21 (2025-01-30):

"connector1Length must be a number" in file vacuum-hose-adapter-openscad.scad, line 1238

gcoan, 2025-01-30:
I've not used the hose adapter for perhaps a year, so downloaded the latest version today, the vacuum-hose-adapter-openscad.scad and modules/*

Using it with my existing vacuum-hose-adapter-openscad.json I get a compile time error both on the 'design default values' and on selecting any of my existing configurations.

Quit OpenScad, deleted my .json file in case that was the problem, opened again, and I am still getting the same compile error all the time.

Error is:

[ERROR: Assertion 'is_num(connector1Length)' failed: "connector1Length must be a number" in file vacuum-hose-adapter-openscad.scad, line 1238](https://github.com/ostat/vacuum-hose-adapter-openscad/issues/1238,/Users/Geoffrey/Documents/3D%20Printing/Misc%20tools/Vacuum%20hose%20adapters/vacuum-hose-adapter-openscad.scad)
[TRACE: called by 'assert' in file vacuum-hose-adapter-openscad.scad, line 1238](https://github.com/ostat/vacuum-hose-adapter-openscad/issues/1238,/Users/Geoffrey/Documents/3D%20Printing/Misc%20tools/Vacuum%20hose%20adapters/vacuum-hose-adapter-openscad.scad)
[TRACE: called by 'HoseAdapter' in file vacuum-hose-adapter-openscad.scad, line 377](https://github.com/ostat/vacuum-hose-adapter-openscad/issues/377,/Users/Geoffrey/Documents/3D%20Printing/Misc%20tools/Vacuum%20hose%20adapters/vacuum-hose-adapter-openscad.scad)

the error comes from line 1238 where it checks that connector1Length is a number:
  assert(is_num(connector1Length), "connector1Length must be a number");

connector1Length is set to End1Length at line 1080

End1Length default value is set at line 50:
 End1_Length = [15,0];  //0.1

I'm wondering if this is just never going to work?
The examples of is_num https://en.wikibooks.org/wiki/OpenSCAD_User_Manual/Type_Test_Functions in the documentation show that it returns false when passed an array which is what End1_Length and thence connector1Length is set to

Am stumped!

gcoan, 2025-01-31:
Had an idea to check whether I was on the latest version of openscad, and I am, 2021.01 on Mac https://openscad.org/downloads.html

So its not that :-(

gcoan, 2025-01-31:
Yep, that's the problem, commit #a8cf59e that introduces the ability to enter connector diameter and length in mm or inches breaks openscad.

I reverted modules/connector_object.scad https://github.com/ostat/vacuum-hose-adapter-openscad/blob/a53f00a67481a5303e5eae7f2828ebaaa1ec4197/vacuum-hose-adapter-openscad.scad and vacuum-hose-adapter-openscad.scad https://github.com/ostat/vacuum-hose-adapter-openscad/blob/a53f00a67481a5303e5eae7f2828ebaaa1ec4197/vacuum-hose-adapter-openscad.scad to the previous commit versions and I'm no longer getting execution errors

ostat, 2025-02-17:
Thanks for raising, this has been fixed.
I changed the length and diameter so they can be specified in inch or mm. But missed a check.

gcoan, 2025-02-17:
Thanks, I will download the latest code and check it works OK.

Been using my frankenstein version for a while, making magnetic adapters for a larger 63m dust hose.

Really great results with creating the models, different ports such as flanged based for connecting to a tool, straight adapter for my cyclone and tapered for the hose.  All rendered brilliantly, thank you.

Less success with the magnetic coupling though. I bought some 10mm x 3mm neodymium magnets from Amazon, printed the adapters with 11mm holes and glued in with contact adhesive which worked well.
The magnets less successful, with 8 magnets the adapter struggled to hold on, and with the weight of the hose it would easily pull off.
Tried with 16 magnets and it was better but still easily came off.

I have now bought some N52 strength 10mm x 5mm magnets and these are much much stronger.  Even with 4 magnets on the adapter this gives a fairly good hold.  Am waiting for the glue to cure fully on 8 and will test it tomorrow but I think it'll be perfect.
Reason for sharing is that I think you should add the advice about buying N52 strength magnets from a reputable supplier, not cheap ones available online.

ostat, 2025-02-18:
I had a similar issue, the magnets would hold OK, bit some times they would come apart. Others have had better experience.
I tried to come up with a solution with the twist locks.
The idea was to add bolts to the magnetic adapter, that would help hold it with the magnets. Printed a couple, but never finished the idea.

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

gcoan, 2025-02-18:
Thanks, I saw the twist lock connector, was trying to get it to work with just magnets.  As I mentioned, 4 x 10mm x 5mm N52 magnets worked OK most of the time,  I tried today with 8 magnets and they were just too strong!  I struggled to get the connectors apart, had to slide them off each other,  and after a few times the magnets pulled out of the contact adhesive I'd been using so I'll have to try using epoxy glue as you suggested.

I have tonight installed a full re-download of the modules and openscad file, and good news it doesn't crash with the mm/inch problem, but its giving some very weird results.

Here's the preview render of an existing 'cyclone magnetic port' adapter configuration I'd created:

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

And here is the model in Cura as I had rendered it with the previous version:

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

Here's the json config file:
[vacuum-hose-adapter-openscad.json](https://github.com/user-attachments/files/18855606/vacuum-hose-adapter-openscad.json)

In the json file, End1_Length is 22 and End2_Length is 15, but the model in Openscad is saying End1 length is 15 and End2 length is 40 which must be why the model looks so wrong:

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

At the moment I'm not sure what its doing so will have to revert back to the previous version

ostat, 2025-02-19:
That is a side affect of a recent change. Many people want to make adapters for imperial systems, however OpenSCAD is all metric. I changed the length and diameter of the adapters to support both metric and imperial values. This changed the value from a number to a list of two numbers. It breaks loading saved settings for those values.

All other values are still metric only.

Essentially you need to manually re-enter the length and diameter of the adapters.

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

gcoan, 2025-02-19:
> That is a side affect of a recent change.
> ...
> Essentially you need to manually re-enter the length and diameter of the adapters.

Thank you, that explains it, and when I went through the JSON, found the original length and diameter for connector 1 and 2, re-set those back in the latest version, I get the model I was expecting.
Might be worth adding this to the readme that people need to do this if they have any saved model configs.  Although whether anyone reads it, different matter!

I've been through all of my saved models and re-setup the diameter and length,  all good apart from two of them that are not rendering properly, maybe something to do with the changes to bend and taper made recently?

'Belt sander to CTS vacuum' if I render this with the prior software I get:
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

But with the latest software (and diameter and length set back to what they should be):
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

Similar issue on 'TS55 dust port to vacuum', the transition isn't spanning between the two connectors

Thanks

gcoan, 2025-02-19:
Sorry one other issue I forgot to mention, I used to be able to specify diameter and length in decimals of a mm, but can't anymore now. Can this be restored?

Thanks

ostat, 2025-02-19:
If you can share the config I can look at why the bend is not working.

ostat, 2025-02-19:
> Might be worth adding this to the readme that people need to do this if they have any saved model configs. Although whether anyone reads it, different matter!

I didn't consider this would be a problem for people. It makes me reconsider the change. I might change how it works.

Instead of changing the value from a number to a list of numbers, I could add a tick option 'Provide length and diameter in inches'.
Thoughts?

gcoan, 2025-02-20:
> If you can share the config I can look at why the bend is not working.

Config file in an earlier comment https://github.com/ostat/vacuum-hose-adapter-openscad/issues/21#issuecomment-2667166398

Thanks

ostat, 2025-02-20:
I think I see the Issue (issues).

1. A positive taper now always match the measurement. So an outer measurement with a positive taper will go small to large. An Inner measurement will go large to small. A negative value will go the opposite. I the past the taper didn't change for the measurement.  This is better overall (I see a lot of people using adapters with the wrong taper). You will need to adjust your taper.
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
gcoan, 2025-03-09:
Hello again Chris, did you see my feedback above on the cen-tec female adapter?

I've created all the connectors I think I need for the moment apart from one for my table saw.  What I'd like is a 3 port adapter, tapered on one side so I can connect the 63mm table saw dust hose to it,  63mm magnetic on the opposite so I can easily move the 63mm hose to my cyclone adapter between the table saw and the thicknesser, and a 40mm port on the side so I can connect a standard vacuum hose to the crown guard (probably via a blast gate for when I'm not using the crown guard).

Am struggling to get a printable model,  not helped by the max 100mm cube size of my 3D printer....

Discovered that to get an adapter with 3 different ports I need to use hull transition and transition hull connector set to 'hull 3'.
Had to arrange the ports so connector 1 is the tapered 63mm, connector 2 is the magnetic 63mm and connector 3 is the 40mm.

This looks ok-ish, but connector 3 is offset a bit higher than I'd like:
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

But worse, on rotating the model I see that connector 2 is actually blocked:
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

And the cutaway shows the problem that connector 3 is protruding into the body:
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

If I increase transition length to 27 then I resolve this problem but now the overall print is too big for my printer:
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

Here's the file, 'table saw 3 way connector':
[vacuum-hose-adapter-openscad.json](https://github.com/user-attachments/files/19148934/vacuum-hose-adapter-openscad.json)

An earlier attempt at creating this with using transition end2 count set to 2, transition hull centre to disabled and a negative transition length gives more like the compact shape I'm looking for.
This of course has two tapered 63mm connectors, not one tapered and one magnetic.
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

This one isn't perfect either as the negative transition length results in unwanted inner walls :-(
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

ostat, 2025-03-10:
Hi, Its generally better to create a new github issue when discussing a new problem. This better allows us to track and close changes. and for them not to be forgotten.

gcoan, 2025-03-10:
Thanks, you're right, I should have created new github issues for separate discussion items.

The original problem of connector1length not working with the change from mm to mm/inches is resolved

There was 1 [comment you made](https://github.com/ostat/vacuum-hose-adapter-openscad/issues/21#issuecomment-2674651556) a couple of weeks ago

> Sorry to be a pain, I realised I missed a push which I believe should fix the clipping issue.

But I didn't see any subsequent code push so is that still a push you missed or is it all there now?

ostat, 2025-03-10:
It should have been fixed in commit 3d2f84d7.
The calculations was using the wrong end of the connector for the calculation. With the taper it was throwing it off enough that it would cause the clipping.

Closed 2025-03-11.

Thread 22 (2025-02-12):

RecessedRing does not work

pullbox, 2025-02-12:
I installed the latest version but also rolled the last commits back to avoid the connect1Length must be a number.

I am building a hose adapter with a magnetic flange.
I defined a magnetic flange on connector 2 and defined a recessed alignment ring.  When building the model it always has a protruding alignment ring. If you define no alignment ring the model is built correctly with no ring, but otherwise it always builds one.

Please let me know if you need anything additionally.

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

ostat, 2025-02-17:
Hello,
I can see the issue here. The script support three unique connectors.
- Connector 1 is down the bottom.
- Connector 2 is up the top.
- Connector 3 is centre for a multi connector.

I believe the issue here is that you are setting the Alignment ring on connector 2, but looking at connector 1.
Where did you download that version from, I need to update it, its a bit old.

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

pullbox, 2025-02-18:
From Github, but I had to revert back to the previous commit(s) because I
got the integer error, and I saw the previous ticket where someone rolled
back to make it work.

On Mon, Feb 17, 2025 at 4:55 PM chris heazlewood ***@***.***>
wrote:

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

ostat, 2025-02-18:
That integer issue is fixed now.

pullbox, 2025-02-19:
Awesome, thanks I try that.

If you don't mind I have another question unrelated to the issue.

I am building this mag. flange adapters for building hoses I can easily
disconnect from my equipment and move to other equipment.
I created a mag flange that will be attached to another regular flange
and slide into each other between the two hose connectors as these go
through a piece of wood 1/2 to 3/4 inch thick.

My problem is that the size of the mag flange never exactly meets the size
and position of the magnets of my previously built one although I have the
specs of the mag flange identical to the others just the length of the hose
adapter etc. is different.

How can I ensure that they are identical?

On Tue, Feb 18, 2025 at 2:32 PM chris heazlewood ***@***.***>
wrote:

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

ostat, 2025-02-19:
Oh that's not good.
Can you share the config and I will take a look.
Are they off by a little bit or a lot?

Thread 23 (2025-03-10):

issues with hull and intersecting walls

ostat, 2025-03-10:
I've created all the connectors I think I need for the moment apart from one for my table saw. What I'd like is a 3 port adapter, tapered on one side so I can connect the 63mm table saw dust hose to it, 63mm magnetic on the opposite so I can easily move the 63mm hose to my cyclone adapter between the table saw and the thicknesser, and a 40mm port on the side so I can connect a standard vacuum hose to the crown guard (probably via a blast gate for when I'm not using the crown guard).

Am struggling to get a printable model, not helped by the max 100mm cube size of my 3D printer....

Discovered that to get an adapter with 3 different ports I need to use hull transition and transition hull connector set to 'hull 3'.
Had to arrange the ports so connector 1 is the tapered 63mm, connector 2 is the magnetic 63mm and connector 3 is the 40mm.

This looks ok-ish, but connector 3 is offset a bit higher than I'd like:
Image

But worse, on rotating the model I see that connector 2 is actually blocked:
Image

And the cutaway shows the problem that connector 3 is protruding into the body:
Image

If I increase transition length to 27 then I resolve this problem but now the overall print is too big for my printer:
Image

Here's the file, 'table saw 3 way connector':
[vacuum-hose-adapter-openscad.json](https://github.com/user-attachments/files/19148934/vacuum-hose-adapter-openscad.json)

An earlier attempt at creating this with using transition end2 count set to 2, transition hull centre to disabled and a negative transition length gives more like the compact shape I'm looking for.
This of course has two tapered 63mm connectors, not one tapered and one magnetic.
Image

This one isn't perfect either as the negative transition length results in unwanted inner walls :-(
Image

ostat, 2025-03-10:
Hi  @gcoan,
Yes this is a know issue. The objects are all rendered in isolation as a tube, each end and the transition. It would have been better had I first created the outer shape, then subtracted the inner shape. This would have resulted in less errors in the walls.

The hull was an attempt to resolve some of this but its not perfect. I think I can improve some of this with some reordering of the render operations. But there is still a need to layout the objects correctly otherwise the walls will be too thin.

I think this can mostly be resolved using the transition and hull transition settings.

This is what I came up with

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

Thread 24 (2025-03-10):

Cen-Tec adapter improvements

ostat, 2025-03-10:
Original comment
https://github.com/ostat/vacuum-hose-adapter-openscad/issues/21#issuecomment-2683276759

I have used the female Cen-Tec adapter for the first time (am not sure what the male one is, I don't recognise it, the male adapters I have are screw-on to the vacuum hose). A useful addition to be able to print these natively and the tapered connector fitted perfectly to the vacuum nozzle:

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

However, some feedback on it.

Firstly, there is a circular rim protruding on the inside of the adapter. This required a whole load of supports to be printed by Cura to enable safe printing of this rim. I tried increasing the print overhang angle but couldn't get rid of the supports.

The rim is really not needed. I guess its there to act as a stop for the male adapter to bear against, but actually it doesn't add anything as the male adapter stops short of it and has its own stop flange to prevent over-insertion.

None of the other Cen Tec adapters I have printed have a similar stop ring:

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

Secondly, as you can see on the photo of the adapter in use, it fits the male cen tec adapter perfectly, in fact too perfectly. It is actually quite difficult to unclip as the male adapter fits so snugly in the female holes there is little space to get your fingers on to push the lugs in to disconnect the parts.

Compare to this other 3D printed Cen Tec adapter, as you can see the the upper part of the hole fits equally perfectly onto the male lug, but the hole with the finger indent extends further downwards, making it much easier to disconnect after use:

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

And finally, I have a number of cen tec adapters printed with dewalt airlock connectors on them, like this, it would be great if there could be a Dewalt airlock adapter connector in the available connector ends. Is this something that's been requested by anyone else?
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

ostat, 2025-03-10:
> (am not sure what the male one is, I don't recognise it, the male adapters I have are screw-on to the vacuum hose

The Male adapter is the part that goes inside the female adapter of the same adapter type. Printing the two should allow them, to connect together.

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

I think this was on the reference model. I thought perhaps having it would allow for less air to slip thought?  Removing it not a problem if its not needed.

> Secondly, as you can see on the photo of the adapter in use, it fits the male cen tec adapter perfectly, in fact too perfectly. It is actually quite difficult to unclip as the male adapter fits so snugly in the female holes there is little space to get your fingers on to push the lugs in to disconnect the parts.
>
> Compare to this other 3D printed Cen Tec adapter, as you can see the the upper part of the hole fits equally perfectly onto the male lug, but the hole with the finger indent extends further downwards, making it much easier to disconnect after use:

I think we can elongate the hole below the clip?

I think it was @landrypm in #7 who helped test the cen-tec adapters.
and @vifino who helped with the male side in #12
I dont use the system so would be interested in hearing from them as well in terms of the suggested changes.

gcoan, 2025-03-10:
This is the model of the cen-tec to dewalt airlock that I have been using https://www.thingiverse.com/thing:4742701

Focussing on the can-tec part you can see the larger finger hole I mentioned and no inner ring.  I'll share a better photo of a cen-tec male connected to it, and you can see how the male doesn't even reach the ring

Looking again at #12 I think I understand what the male side is, it will fit inside a female cen-tec but needs a locking ring that fits in the groove in the male part, and its the locking ring that engages with the holes in the female part.
I think you can buy the locking ring as a spare part from cen-tec, but searching around I've found this model that includes the ring https://www.printables.com/model/967495-quick-connect-clip-cen-tec-compatible which would be needed to complete the male part.

If @vifino confirms, might be worth highlighting this in the documentation

gcoan, 2025-03-10:
Some more photos of the female centec to Dewalt I've been using

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

The inner ring I mentioned. The Dewalt port adapter (bottom) has an inner ring which is much bigger than the ostat one (top)
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

The ostat ring is small in comparison
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

But doesn't actually do anything. It's 25mm inside the adapter but the male adapter is 24mm high so doesn't actually touch it

The larger ring on the Dewalt adapter is I think to provide the base for the Dewalt airlock to bear against
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

Another photo of the larger side finger hole that's much easier to disconnect
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

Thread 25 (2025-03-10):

Support dewalt airlock connectors

ostat, 2025-03-10:
Original comment by @gcoan

I have a number of cen tec adapters printed with dewalt airlock connectors on them, like this, it would be great if there could be a Dewalt airlock adapter connector in the available connector ends. Is this something that's been requested by anyone else?

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

ostat, 2025-03-10:
hi @gcoan, I cant guarantee, but if you can provide detailed diagrams or samples that you know work, I and investigate modelling the adapter.

gcoan, 2025-03-10:
This is the model that I have been using https://www.thingiverse.com/thing:4742701 for connecting Cen-tec to Dewalt airlock

It comprises of two parts, an inner and an outer.  The inner has little 'tabs' that when you push the outer part on and rotate it, pushes those tabs into the airlock locking ring

I'll post some more photos of what the airlock looks like and the parts of the model

gcoan, 2025-03-10:
More photos of the Dewalt airlock and centec adapter

Two parts assembled together
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

Inner part showing the tabs I mentioned
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

Outer ring
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

Airlock port on a Dewalt palm sander
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

The corner pieces on the Dewalt port locate in the grooves in the inner piece
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

Then the outer ring slides on, turn it an eighth turn and it locks the port onto the tool. You can see the tracks that the outer ring slides down before being turned to lock
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

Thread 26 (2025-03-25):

Parameters used for generated printables models

adamjacobmuller, 2025-03-25:
Hi,

I'm trying to generate some adapters which are similar to and compatible with the magnetic flange on some of the models on printables

for example:

https://www.printables.com/model/283255-100mm-magnetic-vacuum-hose-connector/files

101.6mm(4in)-ID-len40mm_to_100mm-12Magnets-10.5x4mm_transition2mm_straight.stl

Are there JSON files for OpenSCAD which were used to generate these anywhere which I could use to generate custom models which are compatible with it?

Thanks in advance and thank you very much for this project, it's absolutely fantastic!

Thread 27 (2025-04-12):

Hose stops being generated on outside when using inner measurements?

timtucker, 2025-04-12:
For the stops, it looks like the logic only puts them on the inside of a hose connector if the end diameter is smaller than the starting diameter:
```
    if(stopWidth > 0 && stopLength > 0)
    {
      translate([0,0,-fudgeFactor])
      Stopper(
        diameter = innerEndDiameter,
        outer = innerStartDiameter <= innerEndDiameter,
        totalLength = stopLength+fudgeFactor*2,
        taper1 = stopSymmetrical ? 0.4 : 0.5,
        taper2 = stopSymmetrical ? 0.4 : 0,
        wallThickness = wallThickness,
        stopThickness = stopWidth,
        zPosition = length,
        marker = false,
        help = help);
    }
  }
```

**If start and end for a section are the same, it seems like it would make more sense to place them on the inside if the hose is using inner measurement.**

Using some tweaks to the example adapter on Maker World:

- Connector 1:
- End1 Style: Hose
- End1 Measurement: inner
- End1 Diameter: 50mm
- End1 StopThickness: 2mm
- End1 StopLength: 2mm

Results in the stop being generated on the outside of the adapter

vs.

- Connector 1:
- End1 Style: Hose
- End1 Measurement: inner
- End1 Diameter: 50.1mm
- End1 Taper: -0.1mm
- End1 StopThickness: 2mm
- End1 StopLength: 2mm

Results in the stop being generated on the inside of the adapter

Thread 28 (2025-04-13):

offset not working

ostat, 2025-04-13:
from https://makerworld.com/en/models/481868?replyId=1811115&replyType=1

I´m just having one problem with offset transition. I always end up with a situation like this, where the transition is not generated properly, blocking part of connector 2 and creating a gap on the other side.
Am i setting something wrong?

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

ostat, 2025-04-13:
fixed in 3e9881e

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

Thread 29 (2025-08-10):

unable to generate osvac

san3, 2025-08-10:
Hi ostat,

I am unable to generate the osvac connectors.
Neither male not female generate the needed recessi/stubs.
The samples provided in vacuum_hose_adapter_demo.scad do not render correctly either.
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

Using windows and the tried to change to the latest openscad nightly without success.

Thanks for your work !
Regards.

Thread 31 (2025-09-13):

Diameter supporting decimal values

bigntallmike, 2025-09-13:
It seems the diameter doesn't support decimals so my 2.5" hose adapter (or 63.5mm) is slightly more annoying to make. If there is not a specific reason to allow decimal values, it would be pretty easy to patch in I suspect.

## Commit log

2022-09-17 Added fillet and lip to flange. Cleaned up code
    [vacuum-hose-adapter-openscad.scad]
2022-09-17 Reworked flange alignment ring
    [vacuum-hose-adapter-openscad.scad]
2022-09-20 Alignment ring improvements. Stop the clearance from moving the ring.
    [vacuum-hose-adapter-openscad.scad]
2022-09-24 separate modules from sample .scad files.
    [100m_magnet_flange_alignment_ring.stl, 100m_magnet_flange_to_100mm_hose.stl, 100m_magnet_flange_to_50mm_hose.stl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]
2022-09-26 Add support for angled transition.
    [50mm_hose_to_100mm_hose_bent_by_90deg.stl, 50mm_hose_to_30mm_hose_bent_by_45deg.stl, vacuum-hose-adapter-modules.scad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]
2022-10-03 Added support for a tapered bent pipe (sweep transition)
    [vacuum-hose-adapter-modules.scad, vacuum-hose-adapter-openscad.scad, vacuum-hose-adapter-samples.scad]
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2022-10-17 Added support for flange with screw holes that would screw to the side of a box.
    [vacuum-hose-adapter-modules.scad, vacuum-hose-adapter-openscad.scad, vacuum-hose-adapter-samples.scad]
2022-10-18 Moved screw holes in flange to avoid being under the bent pipe.
    [vacuum-hose-adapter-modules.scad, vacuum-hose-adapter-samples.scad]
2022-10-27 added dyson v6 and nozzle ends
    [vacuum-hose-adapter-modules.scad, vacuum-hose-adapter-openscad.scad]
2022-11-07 Different wall thickness for ends, improved screw postion on flange, offset transition. sample funnels
    [vacuum-hose-adapter-modules.scad, vacuum-hose-adapter-samples.scad]
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2022-11-17 Added TrasnitionBase, thanks to @ltlowe for code
    [vacuum-hose-adapter-modules.scad]
2022-11-21 Added support for barbs to the hose connector
    [vacuum-hose-adapter-modules.scad]
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2022-12-13 Support for 1 to many connectors
    [vacuum-hose-adapter-modules.scad, vacuum-hose-adapter-samples.scad]
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2023-02-25 style: remove trailing whitespaces
    [funnels.scad, vacuum-hose-adapter-modules.scad, vacuum-hose-adapter-openscad.scad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]
2023-02-25 refact: separate modules from geometry
    [vacuum-hose-adapter-modules.scad, vacuum-hose-adapter-openscad.scad]
2023-02-25 fix(refact): move hidden options to modules
    [vacuum-hose-adapter-modules.scad, vacuum-hose-adapter-openscad.scad, vacuum-hose-adapter-samples.scad]
2023-02-25 fix(samples): remove deprec tapered transition
    [vacuum-hose-adapter-samples.scad]
2023-02-25 fix(samples): correct typos in filenames
    [100mm_magnet_flange_alignment_ring.stl, 100mm_magnet_flange_to_100mm_hose.stl, 100mm_magnet_flange_to_50mm_hose.stl]
2023-03-28 added end cap option
    [vacuum-hose-adapter-modules.scad]
2023-03-30 Clean up typos for funnels
    [funnels.scad]
2023-10-13 added camlock, some refactor
    [ub.scad, vacuum-hose-adapter-modules.scad, vacuum-hose-adapter-openscad.scad]
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2024-03-02 Decreased wall thickness on slots for dw735 connector
    Decreased fixedPinLength and wallThikness for the slots on the dw735 connector.
    Fixes #8
    [vacuum-hose-adapter-modules.scad]
2024-03-04 Magnetic connector, twist lock draft
    [vacuum-hose-adapter-modules.scad]
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2024-03-24 added CNC kitchen inserts
    [connector_magnetic.scad]
2024-03-24 error handling
    [modules_utility.scad]
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2024-03-24 improved handling of adapter defaults
    [connector_camlock.scad, connector_common.scad, connector_dw735.scad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]
2024-04-08 rework the caliper display
    [connector_common.scad, ub.scad, vacuum-hose-adapter-modules.scad]
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2024-05-15 Added osVAC connectors, draft version
    [connector_common_post.scad, connector_osvac.scad, vacuum-hose-adapter-openscad.scad]
2024-05-15 Added text option to extensions
    [vacuum-hose-adapter-openscad.scad]
2024-05-15 refactor, split utility in to two files
    [connector_centec.scad, connector_dyson.scad, connector_hose.scad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]
2024-05-20 added CenTec male connector
    [connector_centec.scad, connector_common_post.scad, modules_pipe.scad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]
2024-05-26 Added version numbers to connectors
    [connector_camlock.scad, connector_centec.scad, connector_dw735.scad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]
2024-05-26 Improve text placement and size
    [vacuum-hose-adapter-openscad.scad]
2024-05-26 pass $fn to connectors
    [vacuum-hose-adapter-openscad.scad]
2024-05-26 Dyson connector v1.2, improved fitment and printability
    [connector_dyson.scad]
2024-05-26 uplift demo script, Support DerviedScenario, created connector samples
    [vacuum_hose_adapter_demo.scad]
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2024-06-03 added new demo and sample scenarios
    [vacuum_hose_adapter_demo.scad]
2024-06-03 Fix taper so large delta diameter does not cause thin walls
    [connector_nozzle.scad, connector_nozzle_test.scad]
2024-06-03 Fix pipe so large delta diameter does not cause thin walls
    [modules_pipe.scad, modules_pipe_test.scad]
2024-06-03 Better nozzle diameter matching
    [vacuum-hose-adapter-openscad.scad]
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2024-06-06 correct glitching of camlock and dyson
    [connector_camlock.scad, connector_dyson.scad]
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2024-06-20 changed makita version to 0.1 as its not been tested
    [connector_makita.scad, makita_male_sample.stl, vacuum-hose-adapter-openscad.scad]
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2024-06-30 when creating pipes, ensure that the walls have a consistent thickness
    [modules_pipe.scad, modules_pipe_test.scad]
2024-06-30 fix connector includes
    [connector_common_post.scad, vacuum-hose-adapter-openscad.scad]
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2025-01-26 allow the connector diameter and length to be entered in mm or inch.
    [connector_object.scad, vacuum-hose-adapter-openscad.scad]
2025-01-26 correct inch to mm conversion
    [connector_object.scad]
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2025-02-17 resolve 'connector1Length must be a number' bug
    [vacuum-hose-adapter-openscad.scad]
2025-02-20 correct transition length calculation
    [vacuum-hose-adapter-openscad.scad]
2025-02-20 correct use of hose dimension for calculations
    [vacuum-hose-adapter-openscad.scad]
2025-04-13 correct bug related to offset
    [modules_pipe.scad]
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2026-02-27 connector bug
    [connector_object.scad, funnels.scad, vacuum-hose-adapter-basic.scad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]
2026-02-27 fix colors on the combined scripts
    [constants.scad, funnels.scad, vacuum-hose-adapter-basic.scad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]
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2026-04-17 Fix magnetic flange alignment ring option assertion
    [connector_object.scad]
2026-06-15 Support reverse thread
    [connector_dw735.scad, connector_hose.scad, connector_object.scad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]
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2026-07-03 improve the pipe modules to be faster, and support chamfer
    [connector_camlock.scad, connector_centec.scad, connector_dw735.scad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]
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2026-07-11 Fix flat-topped internal hose thread teeth when tooth height < pitch
    ScrewHole cuts internal threads with a ScrewThread whose profile leaves
    the part of each pitch not covered by the tooth as a flat at the root
    radius. When tooth_height < pitch, that flat truncates the tips of the
    remaining material teeth instead of shrinking them.
    InternalHoseThread now cuts with an unmodified full-height (pointy)
    ScrewThread enlarged radially by the depth the tooth lost, then clipped
    back to the intended major radius with an intersection. The clipped
    crests become the flats between teeth on the bore wall, so the material
    teeth shrink while staying pointy, with the requested tooth height and
    flank angle. T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
    [modules_threads.scad]
2026-07-11 Constrain external hose thread tooth height to the pitch
    A tooth height larger than the pitch is geometrically impossible (teeth
    would overlap axially) and produced self-intersecting glitched geometry
    in ExternalHoseThread. Constrain it to the thread pitch, matching how
    values equal to the pitch already behave. The pitch==0 case resolves
    the auto pitch the same way ScrewThread does internally.
    [modules_threads.scad]
2026-07-11 Clarify thread direction labels in the Customizer dropdown
    The "enabled" option cuts a left-hand thread (the helix is mirrored)
    and "reversed" cuts a standard right-hand thread, which the plain
    option names did not convey. Use Customizer value:label syntax to
    display "enabled (left-hand)" and "standard (right-hand)" while
    keeping the stored values unchanged, so existing presets and the
    thread-generation logic are unaffected.
    Swapping the behavior instead, so that "enabled" cuts the right-hand
    thread users would expect by default, was considered and rejected:
    it would silently reverse the thread direction in every existing
    preset and previously shared model configuration. Relabeling
    document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
    [vacuum-hose-adapter.scad]
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2026-07-26 add bosch orbital sander connector
    original code by user @tjsoco https://www.printables.com/model/794035-bosch-ros20vs-sandervacuum-adapter-openscad
    [connector_bosch_sander.scad, connector_common_post.scad, connectors.scad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]
2026-07-26 add bosch connector sample
    stl is low resolution (fn=36) to keep the file size small; the bayonet grooves are geometry-heavy. render a higher-fn export yourself for printing.
    [bosch_sander_sample_low_res.stl]
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2026-07-29 reworked the bosh sander, so it should work in the browser
    [connector_bosch_sander.scad, vacuum-hose-adapter.scad]
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2026-07-30 fix some issues with the magnet flange
    [connector_magnetic.scad, connector_object.scad, funnels.scad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]
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2026-07-31 correct gap on festool adapter
    [connector_festool.scad, connector_object.scad, connectors.scad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]
2026-08-04 added a slip ring option
    moved some hose options in to extensions section
    [connector_camlock.scad, connector_hose.scad, connector_object.scad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]
2026-08-04 allow debug and calipers without preview (for online tools)
    [funnels.scad, vacuum-hose-adapter-basic.scad, vacuum-hose-adapter.scad]
2026-08-05 add supports to slipring to prevent sagging
    [connector_object.scad, funnels.scad, modules_slipring.scad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]
2026-08-13 feat(connectors): add Kobalt saw dust outlet connector module
    [connector_kobalt.scad, connectors.scad, vacuum-hose-adapter.scad]
2026-08-13 feat(connectors): add Rigid NXT shop vac hose connector module
    [connector_rigid_nxt.scad, connectors.scad, vacuum-hose-adapter.scad]
2026-08-13 fix(threads): fix mirror([0,0,0]) bug and direct difference internal thread cutout for female hose connectors
    [connector_hose.scad, modules_threads.scad]
2026-08-13 fix(rebase): resolve syntax error and translate parameters post rebase
    [modules_threads.scad, vacuum-hose-adapter.scad]
2026-08-14 feat(threads): add optional RoundScrewThread profile support with customizable tooth height and width
    [connector_hose.scad, connector_object.scad, modules_threads.scad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]
2026-08-15 Fix lock bump regression in BayonetSlotConnector
    The bump that creates the twist lock has not been generated since
    ce1cc0c, when connector_osvac was refactored onto this module. The
    module takes lockBumpDepth, asserts on it and reports it in help, but
    never referenced it in the geometry, so every female it builds has a
    plain full depth channel and no lock.
    Before ce1cc0c osVacFemaleConnector built the bump itself by cutting
    the lock pocket shallower than the channel, reaching
    cutoutRadius - cutoutDepthx + cutoutBumpDepthx. This restores that,
    adding the bump back rather than cutting shallower, which suits the
    way the slots are now built as a union of cutters.
    Affects both callers. osVAC as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
    [module_twist_lock_hose.scad]
2026-08-15 fix merge conflicts
    [funnels.scad, vacuum-hose-adapter-basic.scad, vacuum-hose-adapter.scad]
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2026-11-11 Fix stable OpenSCAD parsing and test folder handling
    OpenSCAD 2021.01 rejects trailing commas in module argument lists, even inside disabled demos. Remove five such commas from the slip-ring examples/profile and MagneticConnector signature without changing geometry.
    Declare ScadScriptFolders as string[] so a single explicitly supplied folder remains a collection. An untyped scalar string concatenates paths when another folder is appended with +=; array typing keeps the paths as separate entries. These parsing and input-handling fixes are independent of Oneida support.
2026-11-11 Add Oneida Quick-Clamp connector support
    Implement nominal-size Oneida connectors with a physically verified 5-inch bead profile, fixed dimensional offsets, fit adjustment, and tangent flange backing. Keep sizing and validation in a connector-local OneidaConnectorSettings factory and shared geometry renderer, leaving connector_object.scad unchanged from upstream.
    Add Customizer integration, simple adapter and fit-ring examples, external clamp documentation, and regression coverage for nominal sizes, fit, wall thickness, extensions, and existing connector behavior.
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2026-11-12 Fix shared module parsing in stable OpenSCAD
    Remove trailing argument commas from three slip-ring examples and the magnetic connector signature. OpenSCAD 2021.01 rejects these commas even in disabled examples; the changes do not alter geometry.
2026-11-12 Fix end-cap grids without a center opening
    Clip grid openings with a solid cylinder when the center-hole diameter is zero instead of calling pipe() with an invalid zero inner radius. Preserve annular clipping for positive center holes and cover both branches with a render fixture.
2026-11-12 Repair adapter demo settings and add regression coverage
    Update thread and hull-center modes, forward current stop, alignment-ring and nozzle settings, remove obsolete duplicate sizing code and trailing argument commas, and repair the grid example. Select inner and outer stop measurements explicitly while preserving taper values.
    Exercise representative demo scenarios, assert all stop-side settings, and run grid and CGAL caliper fixtures through the existing renderer.
